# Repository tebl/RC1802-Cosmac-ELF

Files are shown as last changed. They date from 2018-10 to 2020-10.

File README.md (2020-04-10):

# RC1802 Cosmac ELF
There are two ways you can get involved with computers on the nonprofessional level. You can buy one of several reasonably priced hobby computers, with all the added bells and whistles you'd ever want. On the other hand, you can build your own inexpensive system from scratch.

That was rougly the start of the iconic Cosmac ELF-computers history, it was august 1976 and Popular Electronics magazine had just printed the first in a series of tutorials on how everyone could build their own computers using only common parts and the new 1802 processor from RCA.

Back in 2018 this computer still continues to fascinate... several people, definitively me among them so thanks to the glory of the Internet we can still read the original articles online at [American Radio History.Com](https://www.americanradiohistory.com/Popular-Electronics-Guide.htm):
- [1976-08 Build the Cosmac "ELF" Part 1](https://www.americanradiohistory.com/Archive-Poptronics/70s/1976/Poptronics-1976-08.pdf)
- [1976-09 Build the Cosmac "ELF" Part 2](https://www.americanradiohistory.com/Archive-Poptronics/70s/1976/Poptronics-1976-09.pdf)
- [1977-03 How to expand memory, plus more programs](https://www.americanradiohistory.com/Archive-Poptronics/70s/1977/Poptronics-1977-03.pdf)
- [1977-07 Build the PIXIE Graphic Display](https://www.americanradiohistory.com/Archive-Poptronics/70s/1977/Poptronics-1977-07.pdf)

Thankfully someone already made a version of the computer that's available in kit form and in all ways a fantastic piece of kit, that kit is [Lee Hart's 1802 Membership card](http://www.sunrise-ev.com/membershipcard.htm). If you want the whole package, that's the one to get! So, why on earth did I make another one?

Because I wanted the experience on creating one the old fashioned way, also it had a lot of bits and bobs I never could figure out how worked... I don't have a degree in electronics, so every attempt to explain it to me has so far failed so this was my attempt to reduce all the things I didn't understand to just the minimal number of things I don't understand, yet somehow the thing actually works after only five revisions! There were some stupid mistakes done on the first ones, so let's not dig too far back in the commit logs as I'm easily embarrassed.

While the first version had 256 bytes of RAM, this one supports a whopping 64K of addressable memory in the form of two slots that'll take either RAM or ROM! Should be more than enough for anyone, even if you've got ninja skills at toggling in data! Other added features includes extra blinking LEDs, a lot of them!

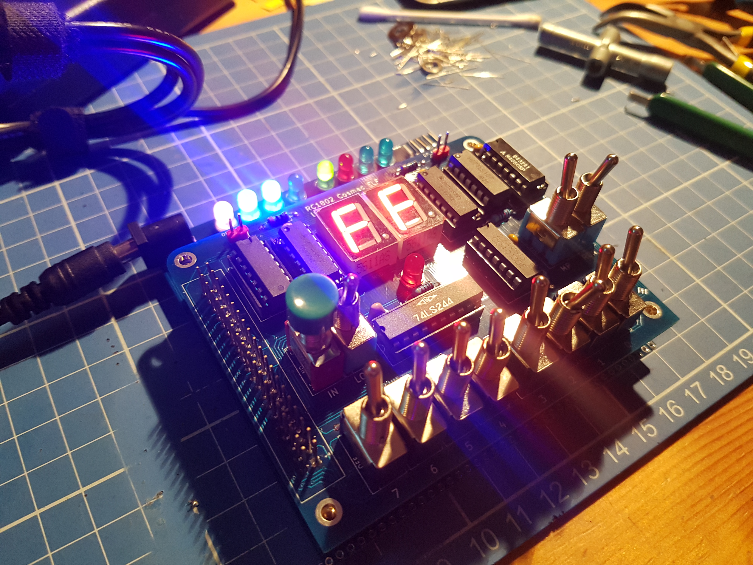
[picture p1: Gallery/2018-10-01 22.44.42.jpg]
RC1802 Computer

RC1802 Modules

## Errata
- UI module revision D had issues where some traces were moved without doing ground plane refill, some lines may appear shorted because of it is. Recommended to replace UI module, but can be cut and rewired according to updated board - see [before](https://github.com/tebl/RC1802-Cosmac-ELF/raw/master/Gallery/1802_ui_d1.PNG) and [after](https://github.com/tebl/RC1802-Cosmac-ELF/raw/master/Gallery/1802_ui_d2.PNG) for reference.
- CPU module revisions D through E had a fault relating to connection of 1802 pin 37 (DMA OUT), mainly that it was never actually connected to anything. Revision F fixes this issue, but you can fix earlier revisions by adding a wire between the bottom of resistor R2 and 1802 pin 37.
- CPU module revision D had **a short** between **GND and VCC**! Later revisions do not have this issue, but if you have this version of the board: please remove pin 40 of the UI connector (top left pin) before attempting to power it up!

## Modules
In order to create a working RC1802 Cosmac ELF computer you will need the following set of modules:
- [CPU Board](https://github.com/tebl/RC1802-Cosmac-ELF/tree/master/RC1802%20CPU) ([order](https://www.pcbway.com/project/shareproject/RC1802_Cosmac_ELF__CPU_module_revision_E_.html?inviteid=88707))
- [User Interface](https://github.com/tebl/RC1802-Cosmac-ELF/tree/master/RC1802%20UI) ([order](https://www.pcbway.com/project/shareproject/RC1802_Cosmac_ELF__UI_module_revision_E_.html?inviteid=88707))

Optional modules:
- [Backplane](https://github.com/tebl/RC6502-Apple-1-Replica/tree/master/RC6502%20Backplane) ([order](https://www.pcbway.com/project/shareproject/RC6502_Apple_1_Replica__Backplane_module_revision_A_.html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))

If you would like to have a copy of one or more modules, what you'll need to do is zip up the contents of the export directory for each module and give that to your favourite PCB fabrication plant. Personally I prefer to use [PCBWay](https://www.pcbway.com/setinvite.aspx?inviteid=88707), each module is only 5$ each and new accounts even get the first one free! Please use the supplied link when signing up to help me support this project, I'll get a small discount on future orders and hopefully I can afford to keep developing new and exciting modules. Even easier, you can just click the orderring-url after each of the modules - that way you'll get something that works on the first try, and you'll support me in a small way for using the URL!

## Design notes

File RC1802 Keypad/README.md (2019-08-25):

# RC1802 Keypad

Toggling in a lot of data, or even just a little bit of data using switches can be a lot of fun... and a lot of work! So in order to keep the fun going I've started experimenting with better switches, this time added the slightly bit newer method of using a hex keypad. This one sort of goes against my design principles of only using the cheapest available alternatives, but only just about by using Gateron keyboard switches instead of those tactile momentary switches. Should be fun!

Note that this is only the mechanical side of things, the logic needed will be made as a separate logic module that hopefully slots in somewhere.

# Schematic
The supplied KiCad files should be sufficient as both a schematic and as a  starting point for ordering PCBs (basically you could just zip the contents of the export folder and upload that on a fabrication site), the schematic is also available in [PDF-format](https://github.com/tebl/RC1802-Cosmac-ELF/raw/master/RC1802%20Keypad/export/RC1802%20Keypad.pdf) and this is what you'll need to print and work your way through this things don't work as expected after assembly.

# BOM
Most parts should be easy to get a hold of from your favourite local electronic component shop though you might have to consider other sources for the older parts such as the CPU and memory. Personally I bought most components with free shipping from China via AliExpress - prices will vary, but I found everything in larger quantities than needed for the cost of a few cups of fancy coffee!

For the pin headers, both male and female - if you can't find the exact pin count, just buy the longer versions and snip off the parts you don't need.

Values in parenthesis is the component amounts that could be considered optional.

| Reference | Item | Count |
| --- | --- | ----- |
| PCB | Fabricate using Gerber files | 1 |
| C1-C6 | 100nF ceramic capacitor | 6 |
| J1 | 2x4 pin header | 1 |
| | 2x4 pin ribbon cable | 1 |
| SW1-SW16 | Gateron 3 or 5 pin switches | 16 |

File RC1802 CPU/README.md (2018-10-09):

# RC1802 CPU Module

Of the two main modules needed for the RC1802 Cosmac ELF computer, this is the main board that includes the RCA 1802 processor along with any RAM and ROM you want. In other words this is the brains of the whole operation! In theory this board by itself should be able to function by itself though the validity of this claim is still lacking some actual testing.

CPU Module

# Schematic
The supplied KiCad files should be sufficient as both a schematic and as a  starting point for ordering PCBs (basically you could just zip the contents of the export folder and upload that on a fabrication site), the schematic is also available in [PDF-format](https://github.com/tebl/RC1802-Cosmac-ELF/raw/master/RC1802%20CPU/export/RC1802%20CPU.pdf) and this is what you'll need to print and work your way through this things don't work as expected after assembly.

# BOM
Most parts should be easy to get a hold of from your favourite local electronic component shop though you might have to consider other sources for the older parts such as the CPU and memory. Personally I bought most components with free shipping from China via AliExpress - prices will vary, but I found everything in larger quantities than needed for the cost of a few cups of fancy coffee! You don't need the newest and fastest components, after all it's going into a 70s-era computer so don't go overboard unless you want to (you can replace 74LS ICs with 74HCT or 74ALS if you want something newer). Most components have been produced by various manufacturers, these mostly do the same thing without any relevant differences though the choice of CPU and PIA could lead to incompatibilities so I've specified the ones I've had success with (probably also the cheapest ones available).

Some vendors will have the same ICs in different form factors, the ones you want will often be specified as being in the form of a DIP/PDIP package. Usually you'll want sockets for each of the ICs as well, a bag of assorted sockets should be easily available without setting you back more than a couple bucks. With the sockets in place, you don't need to dread having to remove an IC later, this leads to easier fault finding and you can even "borrow" them for other projects later! For the pin headers, both male and female - if you can't find the exact pin count, just buy the longer versions and snip off the parts you don't need.

Values in parenthesis is the component amounts that could be considered optional.

| Reference | Item | Count |
| --- | --- | ----- |
| PCB | Fabricate using Gerber files ([order](https://www.pcbway.com/project/shareproject/RC1802_Cosmac_ELF__CPU_module_revision_D_.html))  | 1 |
| C1-C6 | 100nF ceramic capacitor | 6 |
| D1-D8 | 5mm LED (assorted colours) | (8) |
| J5 | 1x39 right-angle pin header | (1) |
| J6 | 2x20 pin header | 1 |
| J7 | 3 pin DC barrel connector | 1 |
| J8 | 1x05 pin header | 1 |
| J9 | 1x04 pin header | 1 |
| JP2-JP6 | 1x03 pin header | 5 |
| R1-R7 | 47k ohm resistor | 7 |
| R8-R15 | 220 ohm resistor | (8) |
| U1 | 74LS04 DIP-14 | 1 |
| U2 | CDP1802 CPU DIP-40 | 1 |
| U3 | 74LS240 DIP-20 | (1) |
| U4 | 74LS373 DIP-20 | 1 |
| U5-U6 | 62256 Static RAM DIP-28 | 1 (1) |
| X1 | 1.000Mhz TTL Oscillator, (DIP 14) | 1 |

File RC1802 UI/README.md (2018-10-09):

# RC1802 User Interface Module

Of the two main modules needed for the RC1802 Cosmac ELF computer, this board contains all the switches you'll need to toggle in data untill you can toggle no more! Also includes the two seven segment displays used as user feedback and output.

UI Module

# Schematic
The supplied KiCad files should be sufficient as both a schematic and as a  starting point for ordering PCBs (basically you could just zip the contents of the export folder and upload that on a fabrication site), the schematic is also available in [PDF-format](https://github.com/tebl/RC1802-Cosmac-ELF/raw/master/RC1802%20UI/export/RC1802%20UI.pdf) and this is what you'll need to print and work your way through this things don't work as expected after assembly.

# BOM
Most parts should be easy to get a hold of from your favourite local electronic component shop though you might have to consider other sources for the older parts such as the CPU and memory. Personally I bought most components with free shipping from China via AliExpress - prices will vary, but I found everything in larger quantities than needed for the cost of a few cups of fancy coffee! You don't need the newest and fastest components, after all it's going into a 70s-era computer so don't go overboard unless you want to (you can replace 74LS ICs with 74HCT or 74ALS if you want something newer). Most components have been produced by various manufacturers, these mostly do the same thing without any relevant differences though the choice of CPU and PIA could lead to incompatibilities so I've specified the ones I've had success with (probably also the cheapest ones available).

Some vendors will have the same ICs in different form factors, the ones you want will often be specified as being in the form of a DIP/PDIP package. Usually you'll want sockets for each of the ICs as well, a bag of assorted sockets should be easily available without setting you back more than a couple bucks. With the sockets in place, you don't need to dread having to remove an IC later, this leads to easier fault finding and you can even "borrow" them for other projects later! For the pin headers, both male and female - if you can't find the exact pin count, just buy the longer versions and snip off the parts you don't need.

Values in parenthesis is the component amounts that could be considered optional.

| Reference | Item | Count |
| --- | --- | ----- |
| PCB | Fabricate using Gerber files ([order](https://www.pcbway.com/project/shareproject/W217819ASE8_RC1802_UI.html))  | 1 |
| C1-C7 | 100nF ceramic capacitor | 7 |
| D1 | 5mm LED (assorted colours) | 1 |
| D2-D7 | 1N4148 DO-35 | 1 |
| J6 | 2x20 female pin header | 1 |
| JP1-JP2 | 1x02 pin header | (2) |
| AFF1,AFF2 | 7-segment display (common cathode) | 2 |
| R1 | 470 ohm resistor | 1 |
| R2,R3 | 47k ohm resistor | 2 |
| R4,R5 | 330 ohm resistor | 2 |
| SW1, SW3-SW12| 3-pin SPDT mini toggle switch | 11 |
| SW2 | 3-pin SPDT momentary button NO-COM-NC | 1 |
| U1 | 74LS04 DIP-14 | 1 |
| U2 | CD4050 DIP-16 | 1 |
| U3 | CD4013 DIP-14 | 1 |
| U4 | 74LS10 DIP-14 | 1 |
| U5,U7 | MC14495P1 DIP-14 | 2 |
| U6 | 74LS244 DIP-20 | 1 |

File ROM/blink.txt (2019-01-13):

Flash blink.hex to 28C256 (yes, I know thats about 99,9% waste of space). Put into slot mapped into low memory to run the code directly (WE switch for this slot in the upper position), this is done by raising toggle switch marked RUN.

If used with slot mapped to upper memory, need to toggle in a short program into lower RAM memory (WE switch for this slot in the lower position) to jump to $8000 (address 8000 in hex). To do this, put all switches (LOAD/MP/RUN) in lower position. Then raise LOAD switch, then toggle in the data listed below. Push IN after each line/byte, the hex display should echo the same byte after.

HEX Binary    Comment
C0  1100 0000 LBR
80  1000 0000 80
00  0000 0000 00

Finish data entry by lowering LOAD switch, to verify that data entered is correct start by raising switch MP (Memory Protect) and then raising LOAD again. Press IN to have the RC6502 computer echo back each byte of data. To correct changes you need to toggle (down and then up again) the LOAD switch to reset the program counter. Keep MP raised and step through until the byte BEFORE the one with the error, lower the MP switch and input the correct byte. Push IN and see that the correct byte was now echoed back, if only changing that one byte - raise the MP switch again and use IN to step through the remaining data.

When satisfied, lower all switches and then raise the RUN switch to have the computer execute the data entered into RAM. It will now jump to the ROM mapped into high memory, if it everything works as expected you should see the computer start to blink it's Q-led.

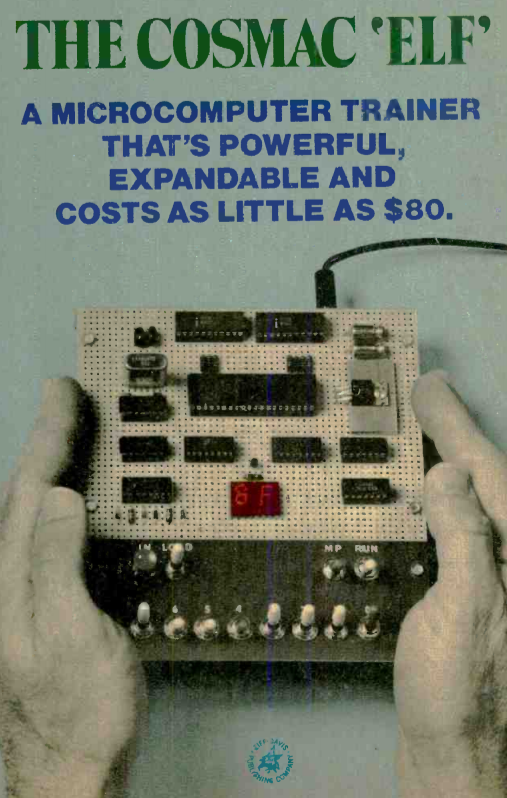
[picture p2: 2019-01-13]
Gallery/Popular Electronics 1976-08 (clipped).PNG

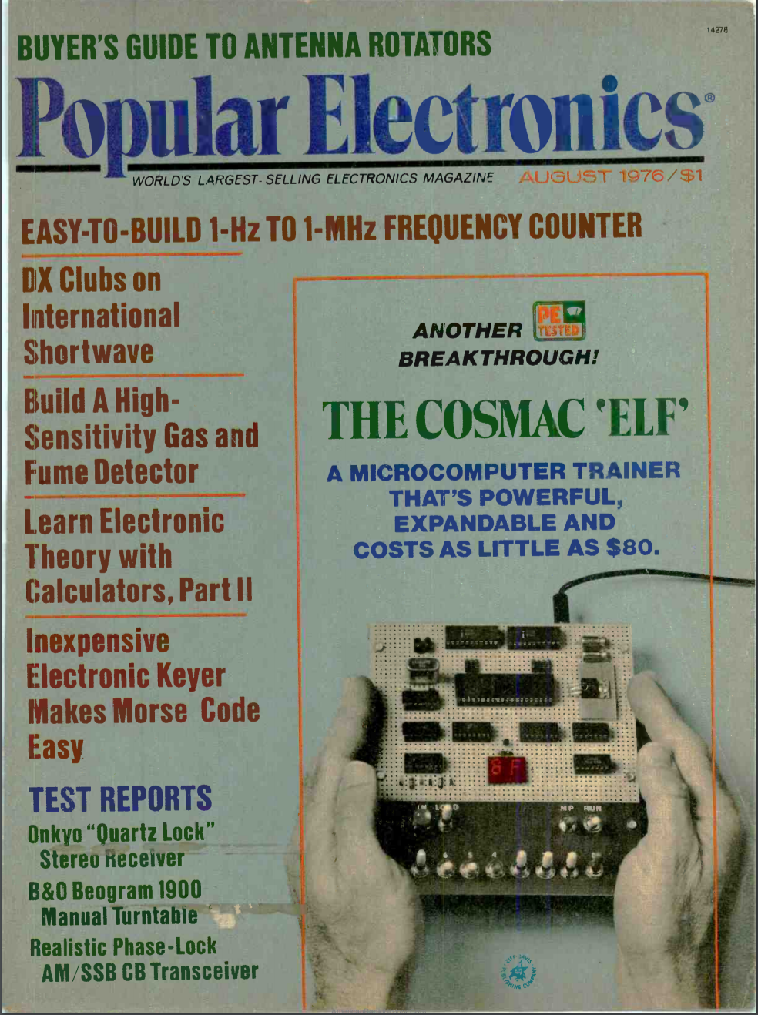
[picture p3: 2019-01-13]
Gallery/Popular Electronics 1976-08.PNG

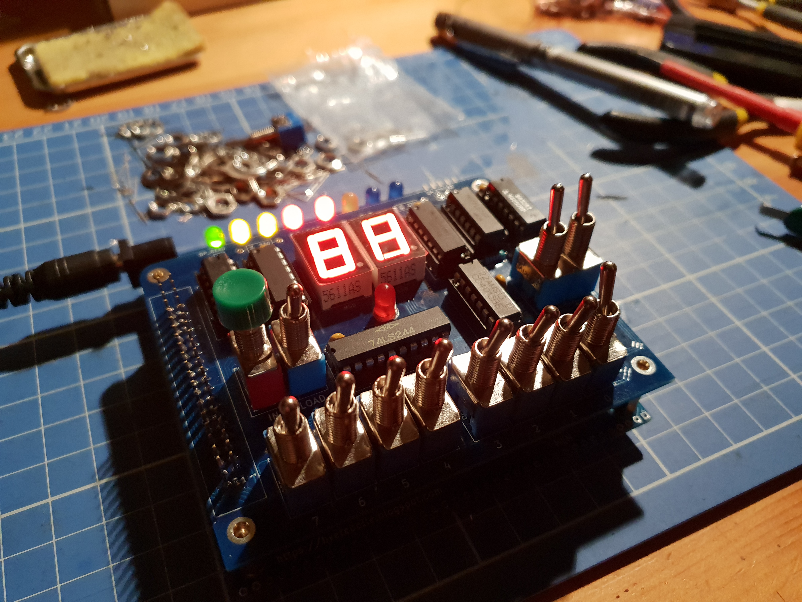
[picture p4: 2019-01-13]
Gallery/2018-11-03 01.10.08.jpg

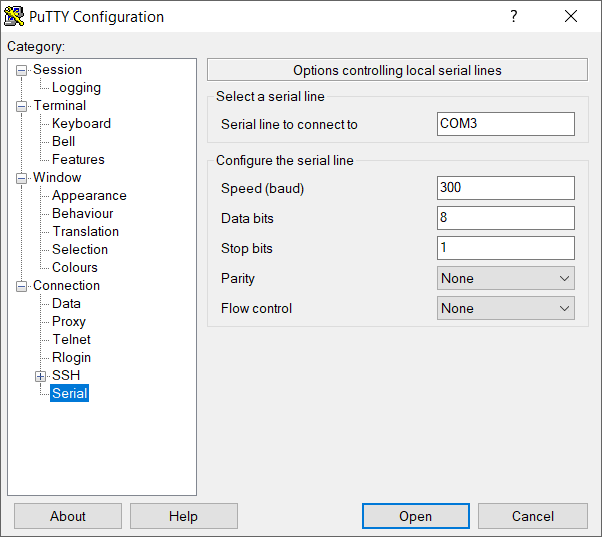
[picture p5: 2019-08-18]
Gallery/Loopback_002.PNG

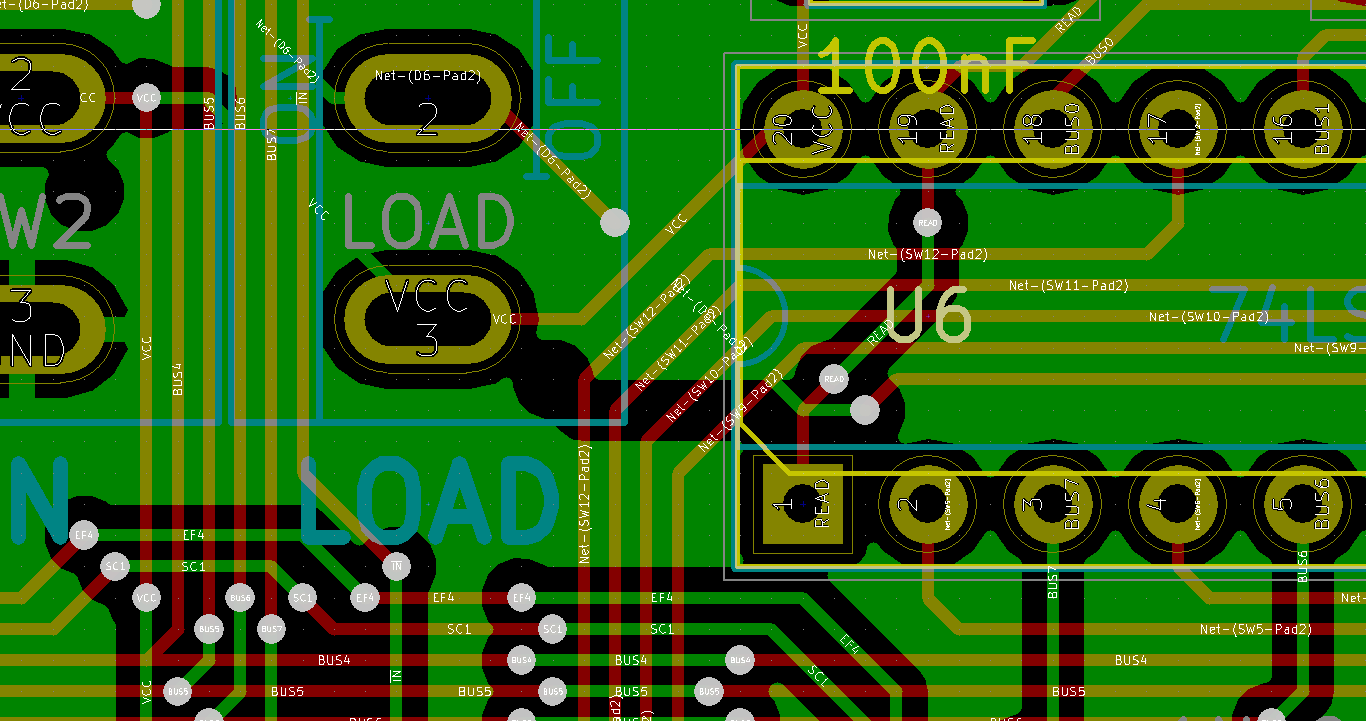
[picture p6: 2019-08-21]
Gallery/1802_ui_d1.PNG

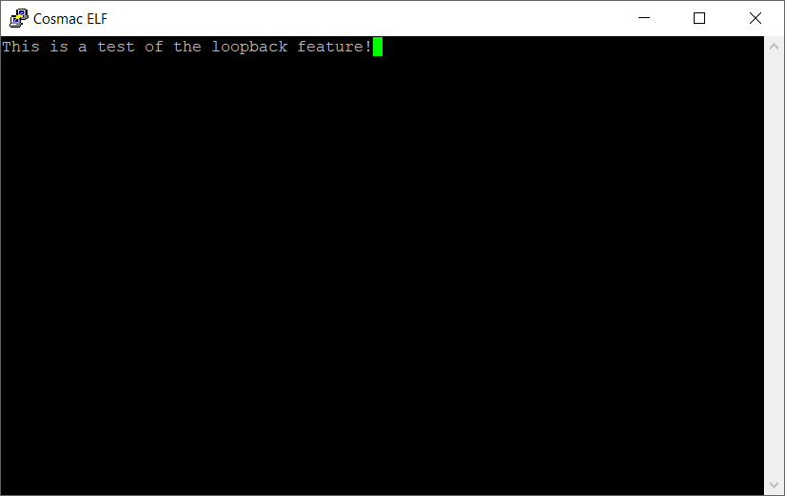
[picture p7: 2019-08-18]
Gallery/Loopback_003.PNG

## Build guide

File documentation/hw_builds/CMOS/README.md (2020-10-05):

# RC1802 CMOS Build
David Madole made a specialized build of the RC1802 using CMOS chips exclusively, the following post from the Cosmac Elf group on [groups.io](https://groups.io/g/cosmacelf) have been included with his permission. Exciting stuff!

## Details
> I completed my RC1802 today with the arrival of the last piece, the MC14495 chips.
>
> I build it as a CMOS version, substituting 74C chips for the 74LS ones and I added pull-up resistors on some of the switches so that inputs aren’t left floating when the switch is in transition since the 74C chips don’t have internal pull-ups. This could be especially important on the MP switch so it doesn’t glitch a write when the switch is flipped.
>
> The options to display the READ and STROBE signals using the decimal points can’t be used as the LED is driven directly from the logic signal and the LED loads the voltage down too much to be seen as a high by the CMOS chips. That would be easy to fix using extra gates on the CD4050 to drive the LEDs separately. I am not sure if I will bother to modify it for that or not since I am not sure that feature is useful to me anyway.
>
> Other than those two things, the conversion to CMOS is pretty painless and all the chips were made in 74C versions (and I even had most of them already in fact). I am probably going to adjust some of the dropping resistor values to decrease the status LED brightness a bit.
>
> Besides toggling in code, I also burned the BASIC3 ROM image from the membership card site to a 27C128 and addressed it at zero and it fired right up into BASIC.  I am using a 1.832 MHz oscillator instead of the 1 MHz specified for a little more speed and also because I may build a PIXIE card for it so I wanted to make sure it runs ok at about that frequency. The BASIC ROM ran 9600 baud fine with this frequency.
>
> I really like the 100mm x 100mm format, I was working on a design of my own for a machine based on that happens to be similar to the RC1802 so when I learned of it I decided to build it first and see how and what I liked on it. It’s a neat little machine, especially as CMOS, I may build an expansion card or two for it.
>
> Photos attached. Some were taken before the MC14495’s arrived so those sockets are empty and the display blank. But there is one I took today with the display in action also.
>
> Special thanks to P. Todd Decker for hooking me up with the boards!
>
> David

## Pictures
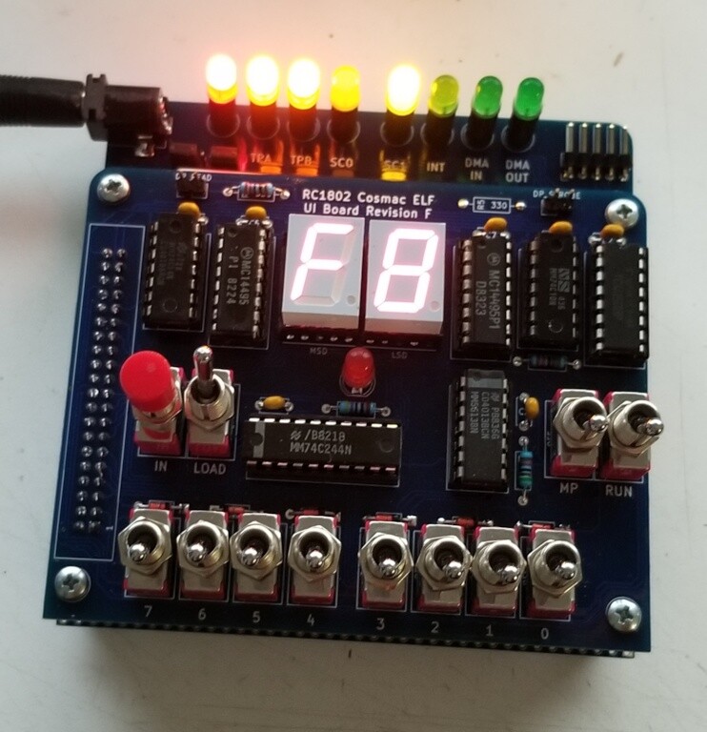
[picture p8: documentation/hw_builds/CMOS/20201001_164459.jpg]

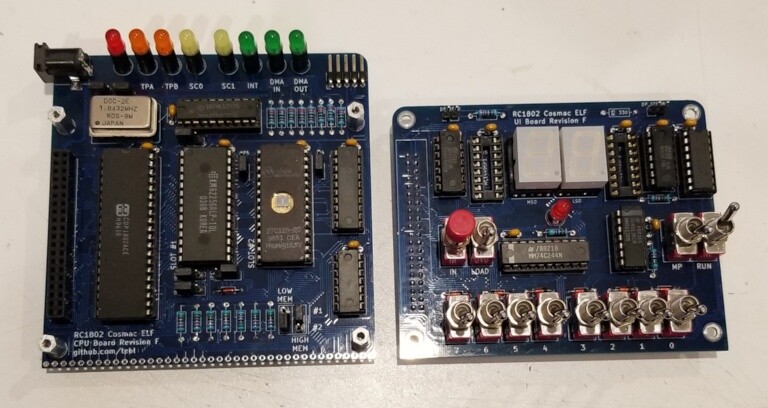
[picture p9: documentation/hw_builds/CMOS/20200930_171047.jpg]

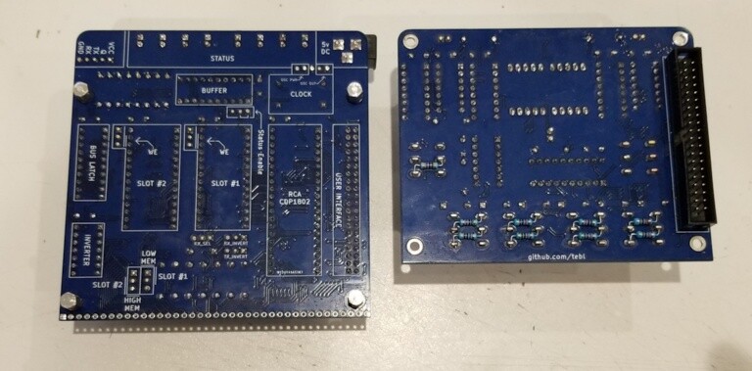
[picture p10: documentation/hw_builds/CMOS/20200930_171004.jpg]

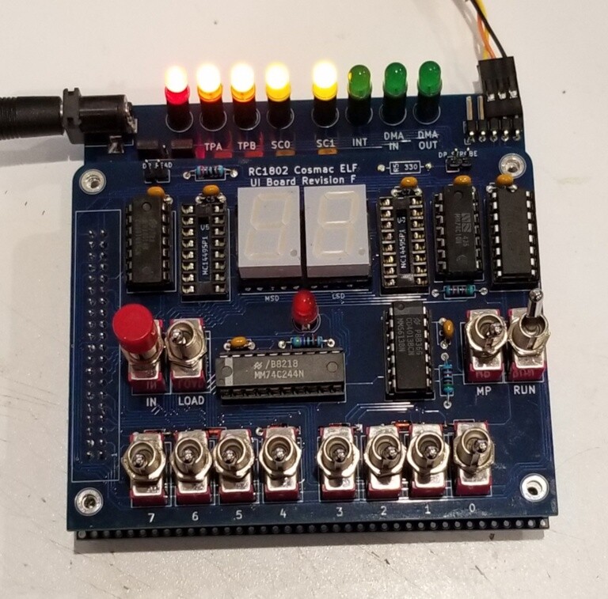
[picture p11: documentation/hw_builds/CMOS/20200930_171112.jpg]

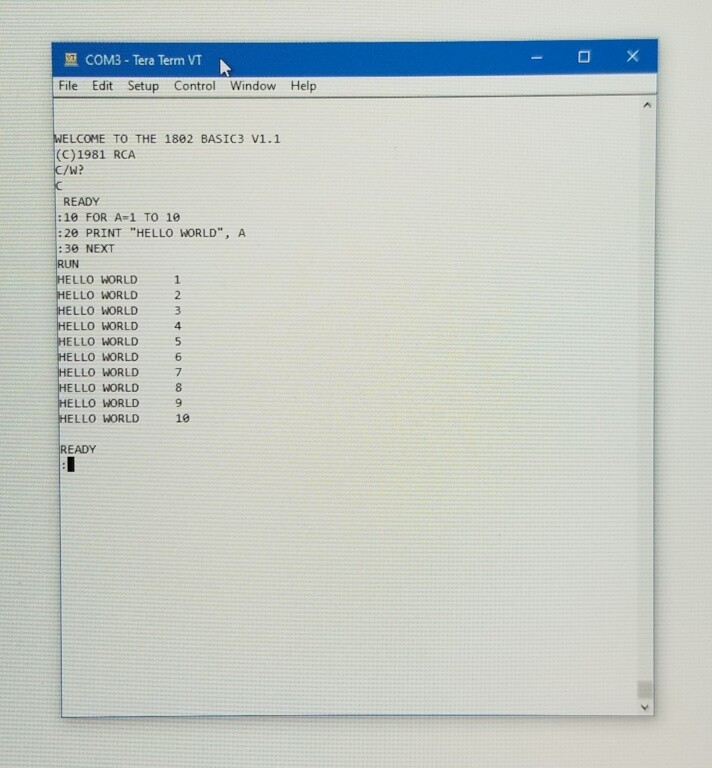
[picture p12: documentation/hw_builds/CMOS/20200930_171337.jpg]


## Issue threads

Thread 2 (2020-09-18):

Serial support - trying to run IDIOT monitor

GrantMeStrength, 2020-09-18:
Are there any special issues with Rev F when it comes to serial support? I’ve been trying to get Serial working for a while now, and have had limited success - it ran once, and I’ve never been able to repeat it. The CPU is definitely running, and a loop back program convinces me the serial ports are working, but IDIOT is stubborn. Any advice welcome!

GrantMeStrength, 2020-09-26:
Ah! Following a discussion on https://groups.io/g/cosmacelf/topics it seems that the logic chips - and U4 on the UI board in particular - should be a CMOS not LS type. Otherwise, replace R3 on the UI board with a 3K3 resistor instead of the 47K. Once I did this, my Elf worked. Thanks!

Closed 2020-09-26.

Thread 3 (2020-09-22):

Digikey BOM Accuracy

ptdecker, 2020-09-22:
Good morning!

I have been trying to pull together a BOM for the RC1802 (all three cards).  Is there any way someone could double-check this list--especially the items in yellow and then in orange--for accuracy?  These specific items are the connectors, switches, and 7-Segment displays.  I have found these particular kinds of parts hard to get correct.

As a side note, I am able to source most of the components from Digikey with the exception of some of the ICs (and, of course, the 1802 itself).

https://docs.google.com/spreadsheets/d/1LfU8H-aynhVCH4n1tYR6aGqn6C8KZxggnxihwcBkzcY/edit?usp=sharing

P. Todd

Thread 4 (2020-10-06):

Question regarding RUN->CLEAR circuitry

hanshuebner, 2020-10-06:
Hey,

I am building your computer, thank you for publishing it!  While working on it, I found this in the schematics of the I/O board:

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

I wonder if this is a mistake or whether something is going on which is beyond my limited knowledge of electronics and CMOS buffers.  It looks as if the input of the buffer is directly connected to the output, so what can the buffer do here?

Thanks again! Hans

dmadole, 2020-10-10:
It is used to debounce the switch. Basically the buffer will hold whatever signal is forced onto it. By shorting the input to VCC or Ground you can override what state it's in already e.g. it's it's high you can force it to low by grounding the input. Yes, this grounds the output also but the CMOS outputs are current limited and it's harmless to do so, especially for the tens of microseconds until the gate changes level.

hanshuebner, 2020-10-11:
Thank you for the explanation!

Closed 2020-10-11.

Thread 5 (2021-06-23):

Resistor values

dmadole, 2021-06-23:
The 47K pull-down resistors in the diode-logic gates are too weak to pull down the LSTTL inputs causing the display and input port to be enabled when they shouldn'tbe . Replace with 4.7K to fix.

Replacing the 47K resistors on the CPU card with 4.7K is a good idea also if the bus is expanded. The 4.7K resistors on both cards are better even when using CMOS.

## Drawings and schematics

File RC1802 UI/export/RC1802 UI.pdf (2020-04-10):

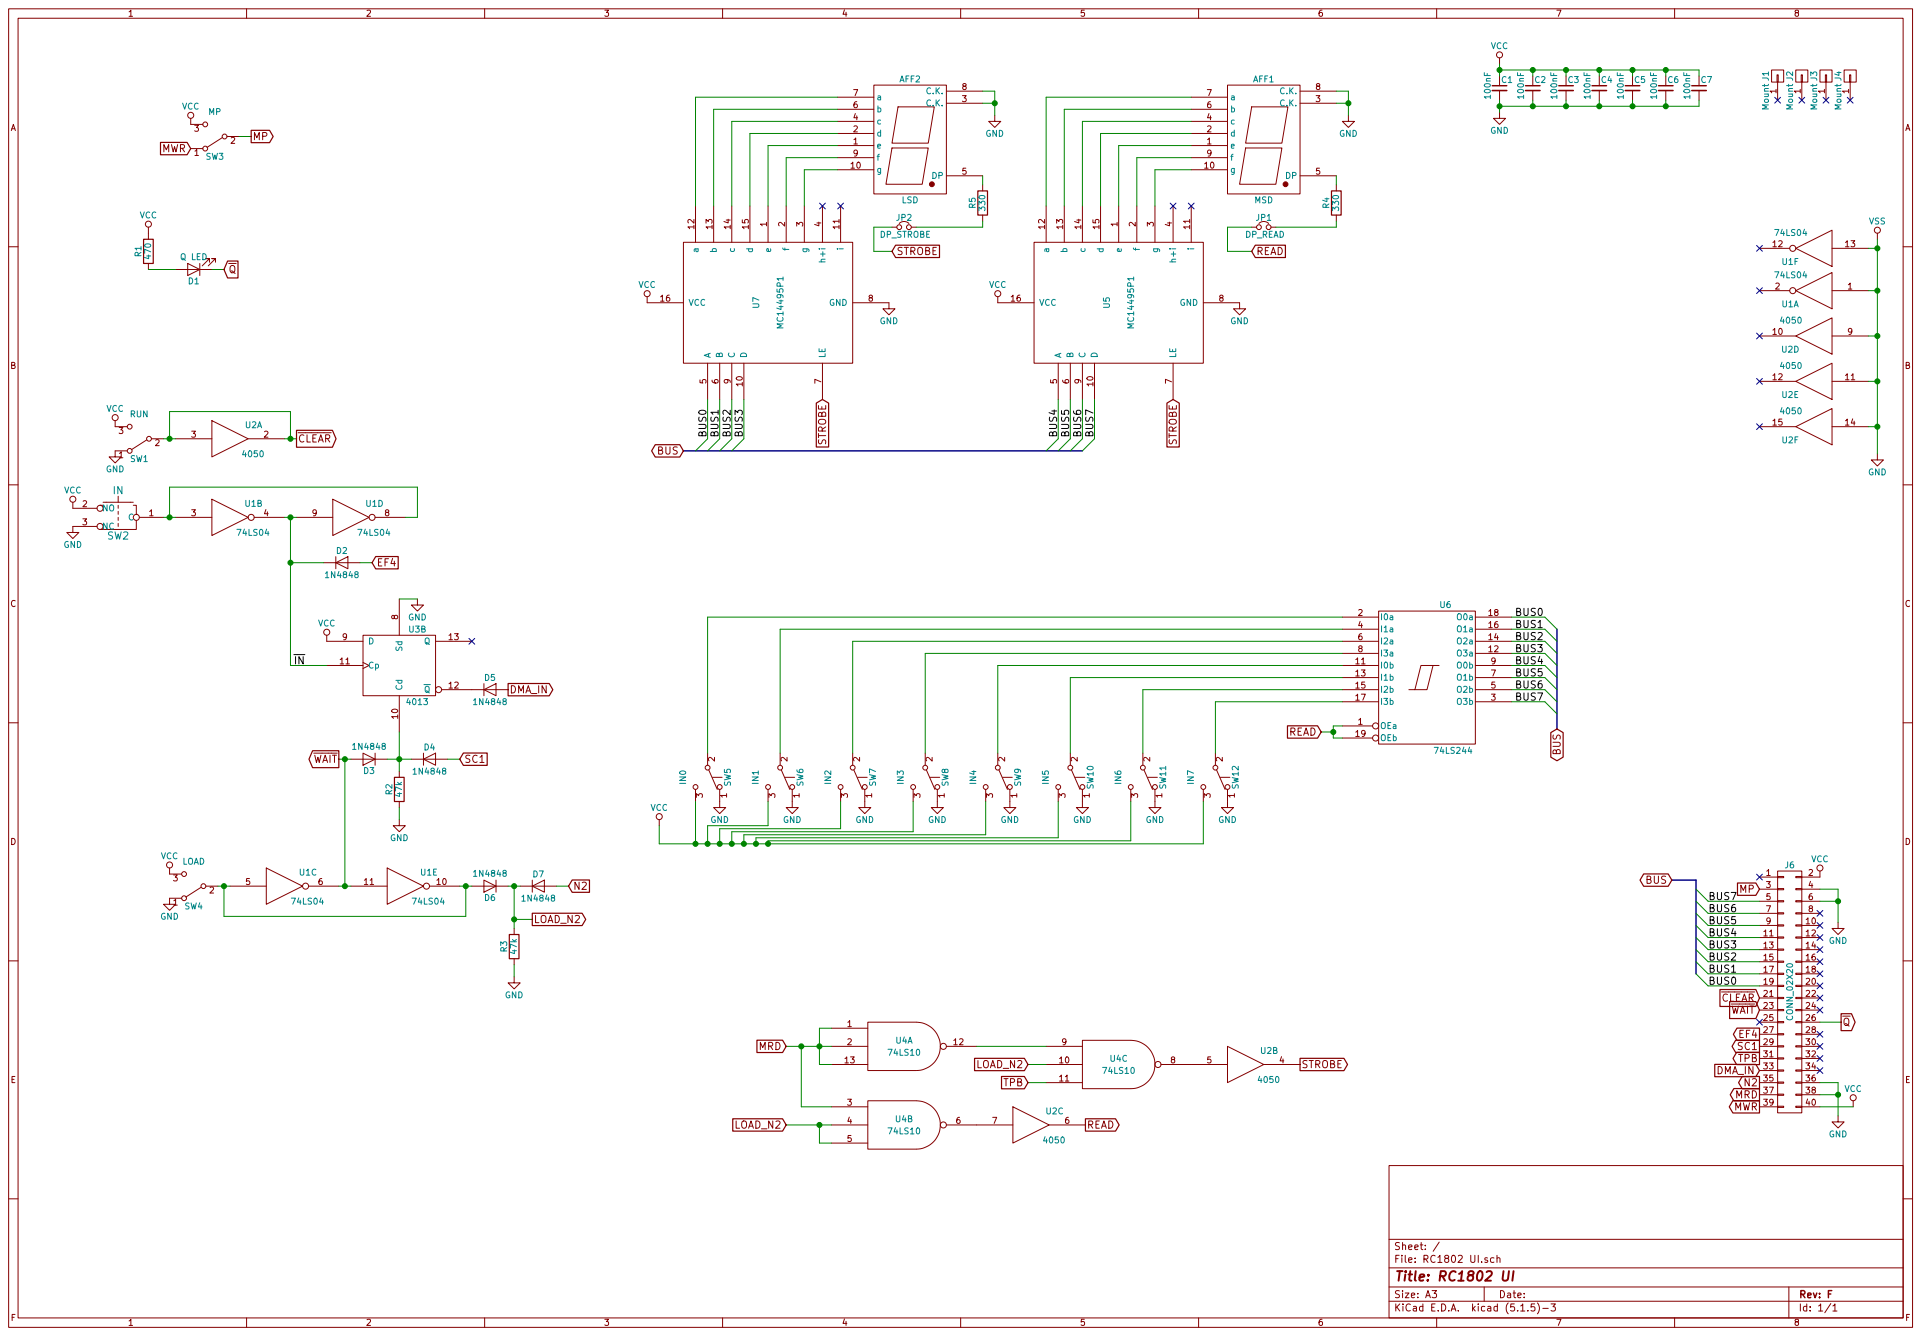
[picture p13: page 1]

1 J1 Mount 1 J2 Mount 1 J3 Mount 1 J4 Mount R1 470

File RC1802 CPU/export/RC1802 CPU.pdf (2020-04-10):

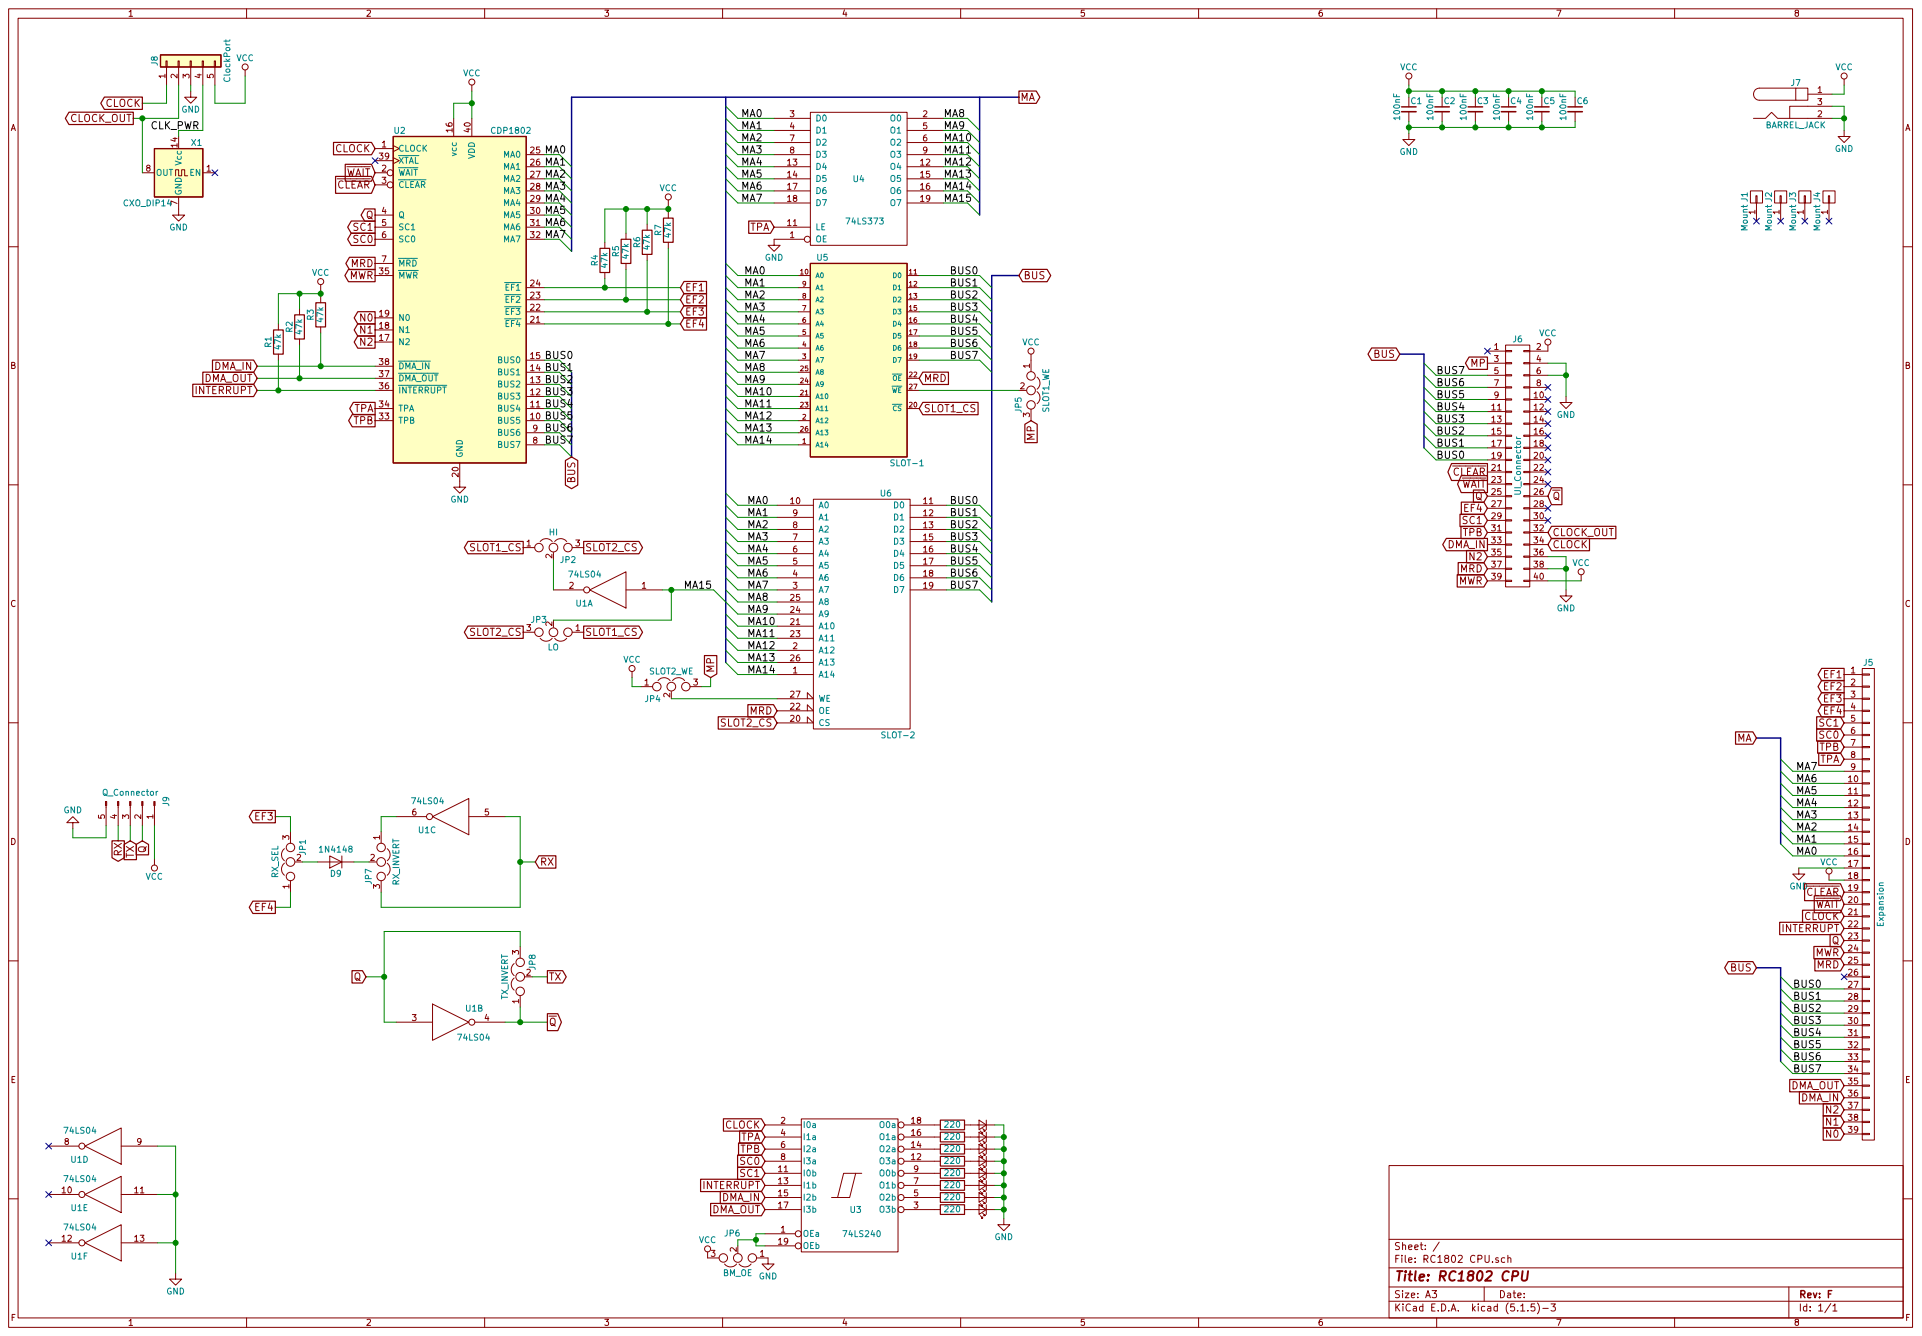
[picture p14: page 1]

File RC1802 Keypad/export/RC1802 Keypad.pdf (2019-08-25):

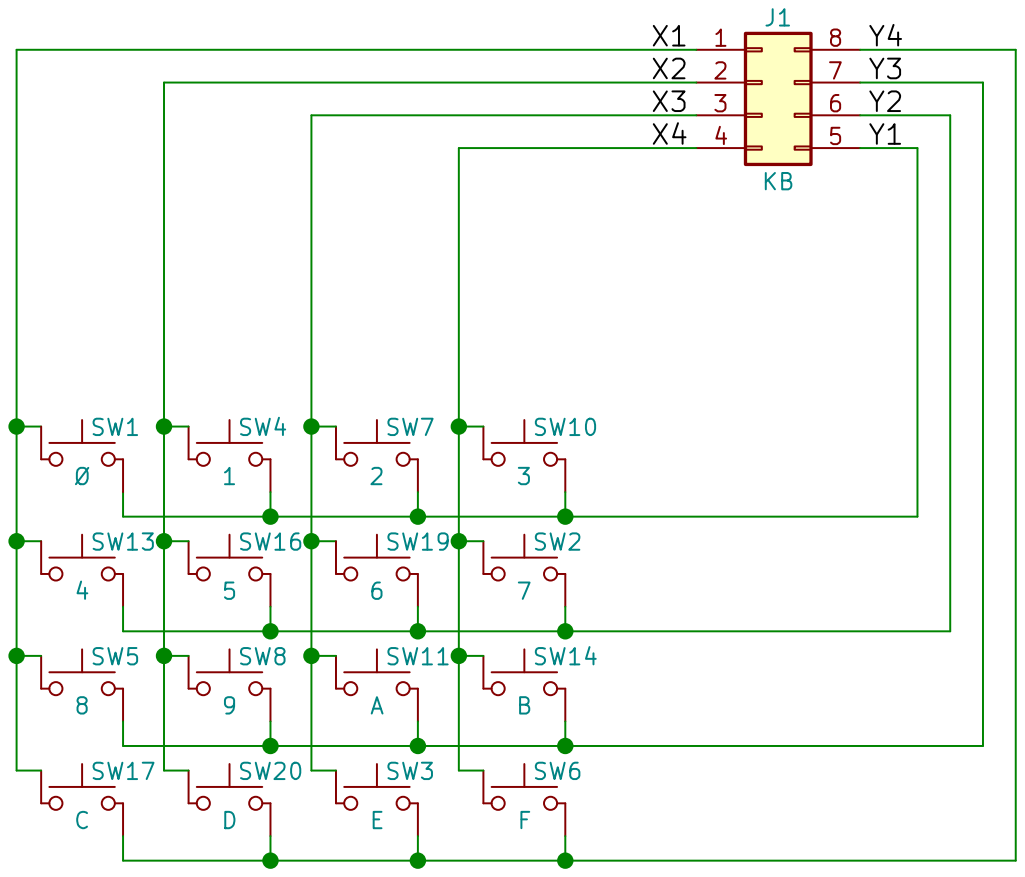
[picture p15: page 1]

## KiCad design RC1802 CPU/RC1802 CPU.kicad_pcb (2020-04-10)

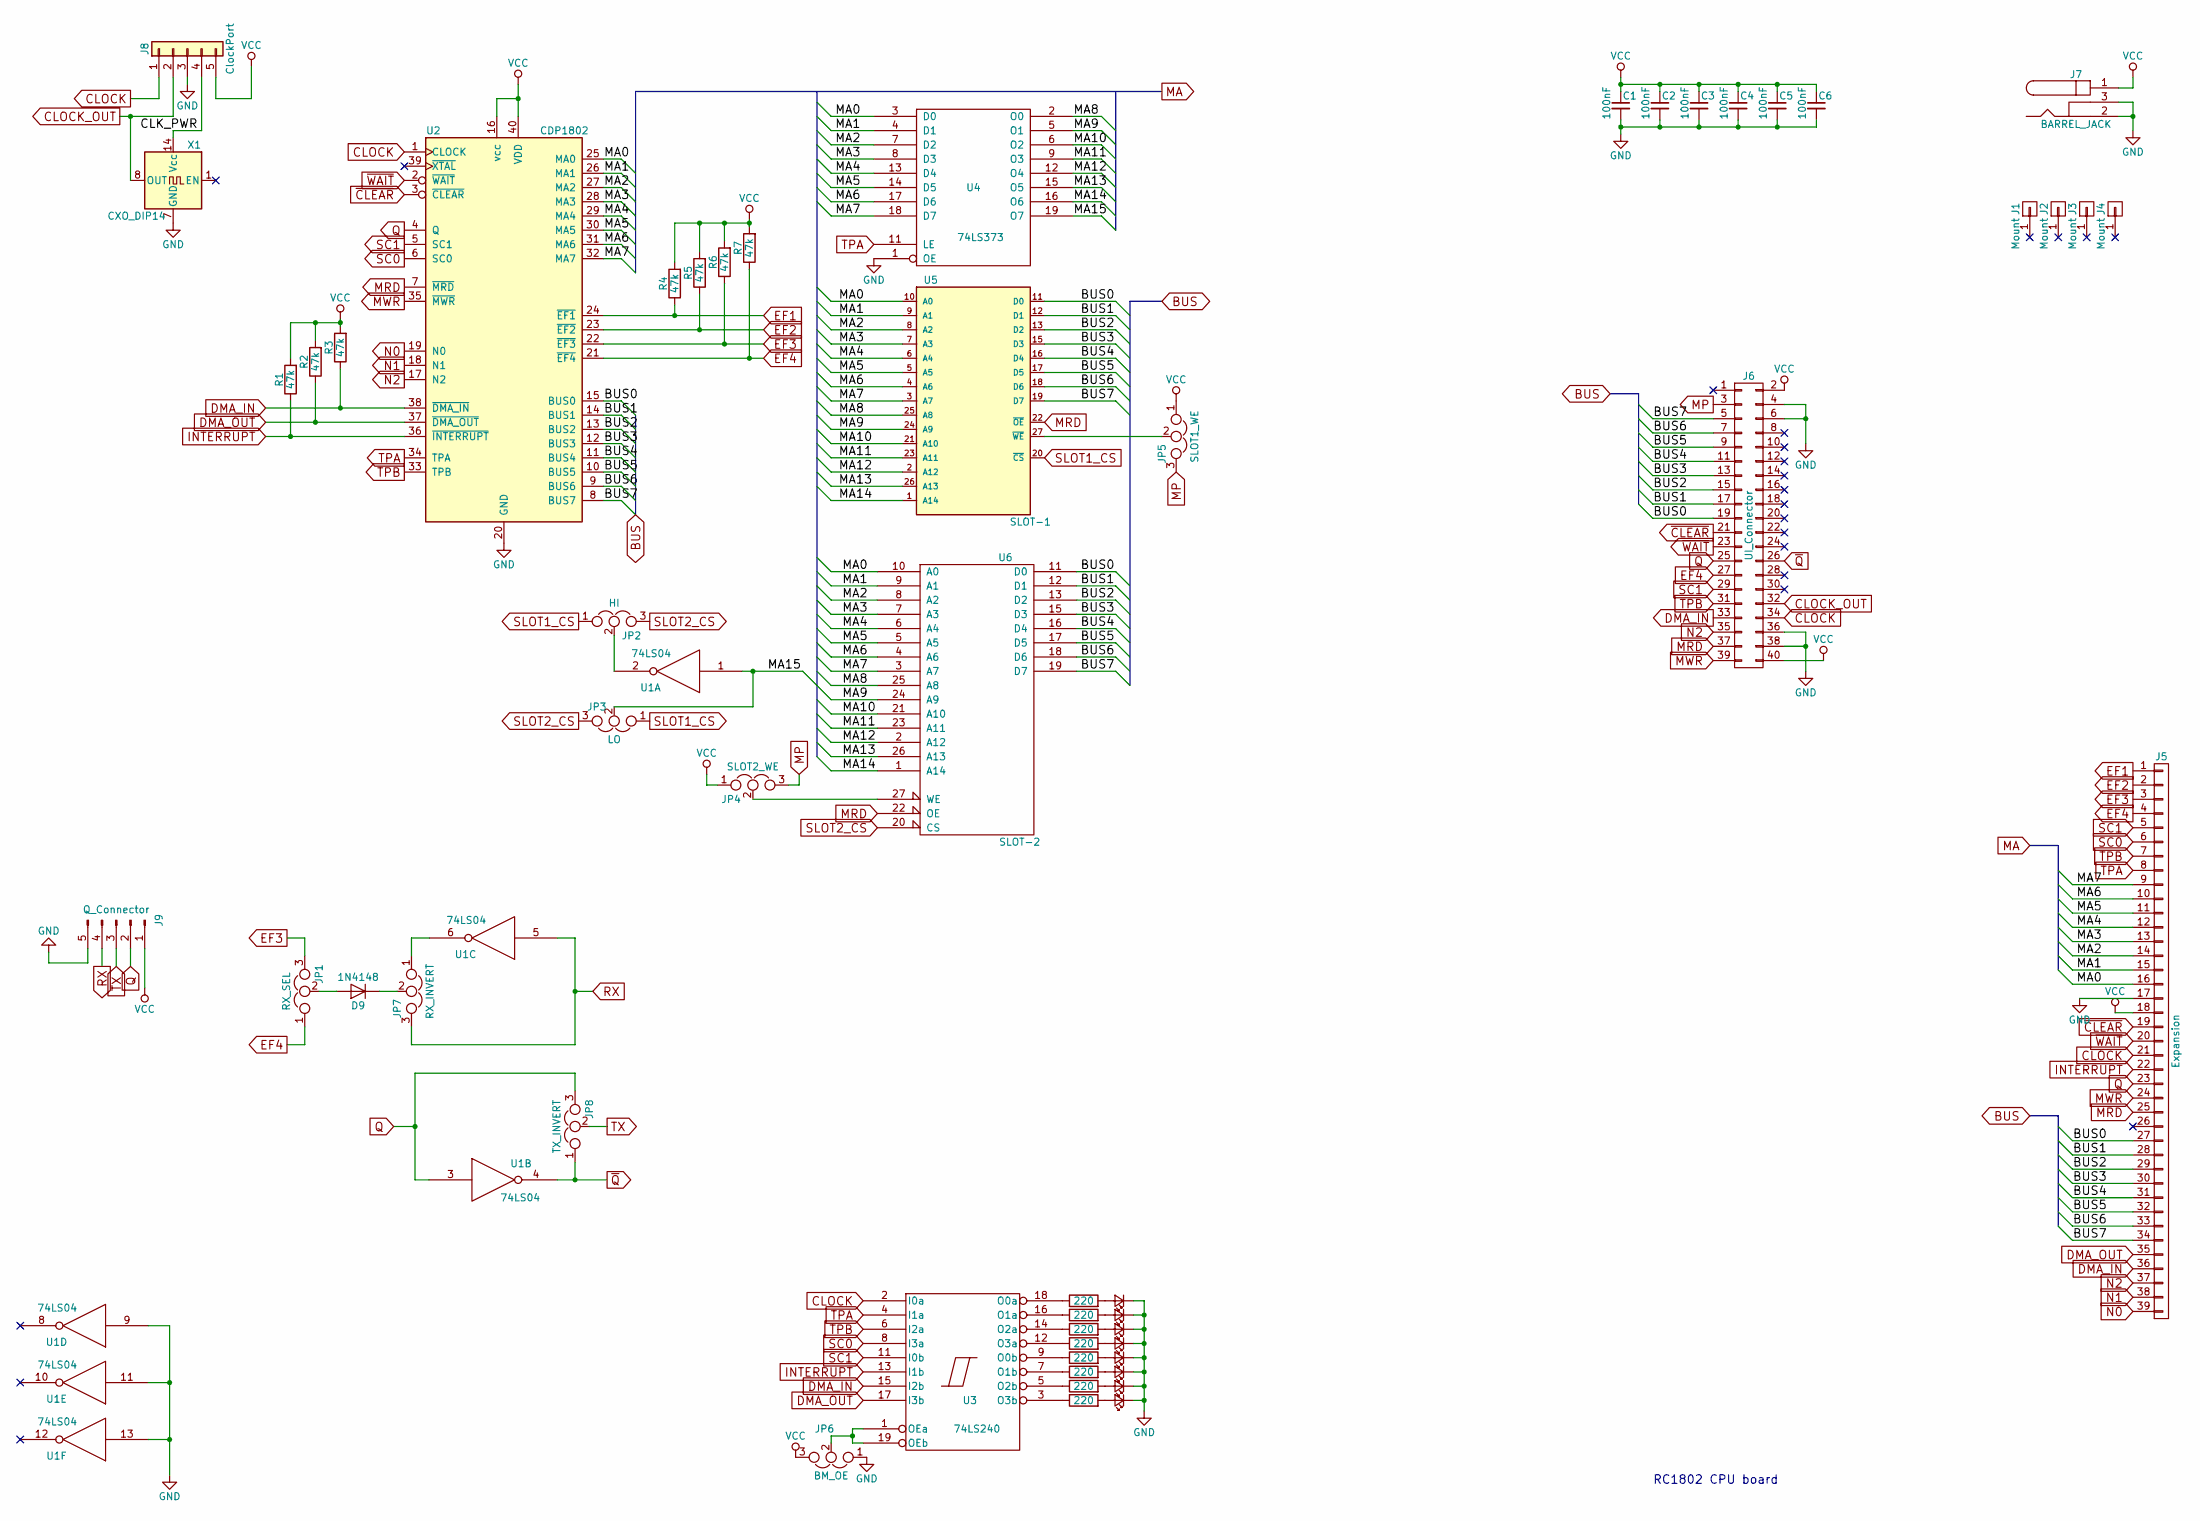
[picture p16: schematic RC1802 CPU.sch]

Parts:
C1, C2, C3, C4, C5, C6: 100nF; C_Disc_D4.7mm_W2.5mm_P5.00mm
D1, D2, D3, D4, D5, D6, D7, D8: LED_Small; LED_D5.0mm
D9: 1N4148; D_DO-35_SOD27_P7.62mm_Horizontal
J1, J2, J3, J4: Mount; 1pin
J5: Expansion; Pin_Header_Angled_1x39_Pitch2.54mm
J6: UI_Connector; Pin_Header_Straight_2x20_Pitch2.54mm
J7: BARREL_JACK
J8: ClockPort; Pin_Header_Straight_1x05_Pitch2.54mm
J9: Q_Connector; Pin_Header_Angled_1x05_Pitch2.54mm
JP1: RX_SEL; Pin_Header_Straight_1x03_Pitch2.54mm
JP2: HI; Pin_Header_Straight_1x03_Pitch2.54mm
JP3: LO; Pin_Header_Straight_1x03_Pitch2.54mm
JP4: SLOT2_WE; Pin_Header_Straight_1x03_Pitch2.54mm
JP5: SLOT1_WE; Pin_Header_Straight_1x03_Pitch2.54mm
JP6: BM_OE; Pin_Header_Straight_1x03_Pitch2.54mm
JP7: RX_INVERT; Pin_Header_Straight_1x03_Pitch2.54mm
JP8: TX_INVERT; Pin_Header_Straight_1x03_Pitch2.54mm
R1, R2, R3, R4, R5, R6, R7: 47k; R_Axial_DIN0207_L6.3mm_D2.5mm_P10.16mm_Horizontal
R8, R9, R10, R11, R12, R13, R14, R15: 220; R_Axial_DIN0207_L6.3mm_D2.5mm_P10.16mm_Horizontal
U1: 74LS04; DIP-14_W7.62mm_Socket
U2: CDP1802; DIP-40_W15.24mm_Socket
U3: 74LS240; DIP-20_W7.62mm_Socket
U4: 74LS373; DIP-20_W7.62mm_Socket
U5: SLOT-1; DIP-28_W15.24mm_Socket
U6: SLOT-2; DIP-28_W15.24mm_Socket
X1: CXO_DIP14; Oscillator_DIP-14

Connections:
/BUS0: J5.27, J6.19, U2.15 (BUS0), U5.11 (D0), U6.11 (D0)
/BUS1: J5.28, J6.17, U2.14 (BUS1), U5.12 (D1), U6.12 (D1)
/BUS2: J5.29, J6.15, U2.13 (BUS2), U5.13 (D2), U6.13 (D2)
/BUS3: J5.30, J6.13, U2.12 (BUS3), U5.15 (D3), U6.15 (D3)
/BUS4: J5.31, J6.11, U2.11 (BUS4), U5.16 (D4), U6.16 (D4)
/BUS5: J5.32, J6.9, U2.10 (BUS5), U5.17 (D5), U6.17 (D5)
/BUS6: J5.33, J6.7, U2.9 (BUS6), U5.18 (D6), U6.18 (D6)
/BUS7: J5.34, J6.5, U2.8 (BUS7), U5.19 (D7), U6.19 (D7)
/CLK_PWR: J8.4, X1.14 (Vcc)
/MA0: J5.16, U2.25 (MA0), U4.3 (D0), U5.10 (A0), U6.10 (A0)
/MA1: J5.15, U2.26 (MA1), U4.4 (D1), U5.9 (A1), U6.9 (A1)
/MA2: J5.14, U2.27 (MA2), U4.7 (D2), U5.8 (A2), U6.8 (A2)
/MA3: J5.13, U2.28 (MA3), U4.8 (D3), U5.7 (A3), U6.7 (A3)
/MA4: J5.12, U2.29 (MA4), U4.13 (D4), U5.6 (A4), U6.6 (A4)
/MA5: J5.11, U2.30 (MA5), U4.14 (D5), U5.5 (A5), U6.5 (A5)
/MA6: J5.10, U2.31 (MA6), U4.17 (D6), U5.4 (A6), U6.4 (A6)
/MA7: J5.9, U2.32 (MA7), U4.18 (D7), U5.3 (A7), U6.3 (A7)
/MA8: U4.2 (O0), U5.25 (A8), U6.25 (A8)
/MA9: U4.5 (O1), U5.24 (A9), U6.24 (A9)
/MA10: U4.6 (O2), U5.21 (A10), U6.21 (A10)
/MA11: U4.9 (O3), U5.23 (A11), U6.23 (A11)
/MA12: U4.12 (O4), U5.2 (A12), U6.2 (A12)
/MA13: U4.15 (O5), U5.26 (A13), U6.26 (A13)
/MA14: U4.16 (O6), U5.1 (A14), U6.1 (A14)
/MA15: JP3.2, U1.1, U4.19 (O7)
CLOCK: J5.21, J6.34, J8.1, U2.1 (CLOCK), U3.2 (I0a)
CLOCK_OUT: J6.32, J8.2, X1.8 (OUT)
DMA_IN: J5.36, J6.33, R3.1, U2.38 (~DMA_IN), U3.15 (I2b)
DMA_OUT: J5.35, R2.1, U2.37 (~DMA_OUT), U3.17 (I3b)
EF1: J5.1, R4.1, U2.24 (~EF1)
EF2: J5.2, R5.1, U2.23 (~EF2)
EF3: J5.3, JP1.3, R6.1, U2.22 (~EF3)
EF4: J5.4, J6.27, JP1.1, R7.1, U2.21 (~EF4)
GND: C1.2, C2.2, C3.2, C4.2, C5.2, C6.2, D1.1 (K), D2.1 (K), D3.1 (K), D4.1 (K), D5.1 (K), D6.1 (K), D7.1 (K), D8.1 (K), J5.17, J6.4, J6.6, J6.36, J6.38, J7.2, J7.3, J8.3, J9.5, JP6.1, U1.7 (GND), U1.9, U1.11, U1.13, U2.20 (GND), U3.10 (GND), U4.1 (OE), U4.10 (GND), U5.14 (GND), U6.14 (GND), X1.7 (GND)
INTERRUPT: J5.22, R1.1, U2.36 (~INTERRUPT), U3.13 (I1b)
MP: J6.3, JP4.3, JP5.3
MRD: J5.25, J6.37, U2.7 (~MRD), U5.22 (~OE), U6.22 (OE)
MWR: J5.24, J6.39, U2.35 (~MWR)
N0: J5.39, U2.19 (N0)
N1: J5.38, U2.18 (N1)
N2: J5.37, J6.35, U2.17 (N2)
unnamed: D1.2 (A), R8.2
unnamed: D2.2 (A), R9.2
unnamed: D3.2 (A), R10.2
unnamed: D4.2 (A), R11.2
unnamed: D5.2 (A), R12.2
unnamed: D6.2 (A), R13.2
unnamed: D7.2 (A), R14.2
unnamed: D8.2 (A), R15.2
unnamed: D9.1 (K), JP7.2
unnamed: D9.2 (A), JP1.2
unnamed: JP2.2, U1.2
unnamed: JP4.2, U6.27 (WE)
unnamed: JP5.2, U5.27 (~WE)
unnamed: JP6.2, U3.1 (OEa), U3.19 (OEb)
unnamed: JP7.1, U1.6
unnamed: R8.1, U3.18 (O0a)
unnamed: R9.1, U3.16 (O1a)
unnamed: R10.1, U3.14 (O2a)
unnamed: R11.1, U3.12 (O3a)
unnamed: R12.1, U3.9 (O0b)
unnamed: R13.1, U3.7 (O1b)
unnamed: R14.1, U3.5 (O2b)
unnamed: R15.1, U3.3 (O3b)
Q: J5.23, J6.25, J9.2, JP8.3, U1.3, U2.4 (Q)
RX: J9.4, JP7.3, U1.5
SC0: J5.6, U2.6 (SC0), U3.8 (I3a)
SC1: J5.5, J6.29, U2.5 (SC1), U3.11 (I0b)
SLOT1_CS: JP2.1, JP3.1, U5.20 (~CS)
SLOT2_CS: JP2.3, JP3.3, U6.20 (CS)
TPA: J5.8, U2.34 (TPA), U3.4 (I1a), U4.11 (LE)
TPB: J5.7, J6.31, U2.33 (TPB), U3.6 (I2a)
TX: J9.3, JP8.2
VCC: C1.1, C2.1, C3.1, C4.1, C5.1, C6.1, J5.18, J6.2, J6.40, J7.1, J8.5, J9.1, JP4.1, JP5.1, JP6.3, R1.2, R2.2, R3.2, R4.2, R5.2, R6.2, R7.2, U1.14 (VCC), U2.16 (vcc), U2.40 (VDD), U3.20 (VCC), U4.20 (VCC), U5.28 (VCC), U6.28 (VCC)
~CLEAR: J5.19, J6.21, U2.3 (~CLEAR)
~Q: J6.26, JP8.1, U1.4
~WAIT: J5.20, J6.23, U2.2 (~WAIT~)

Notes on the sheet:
RC1802 CPU board

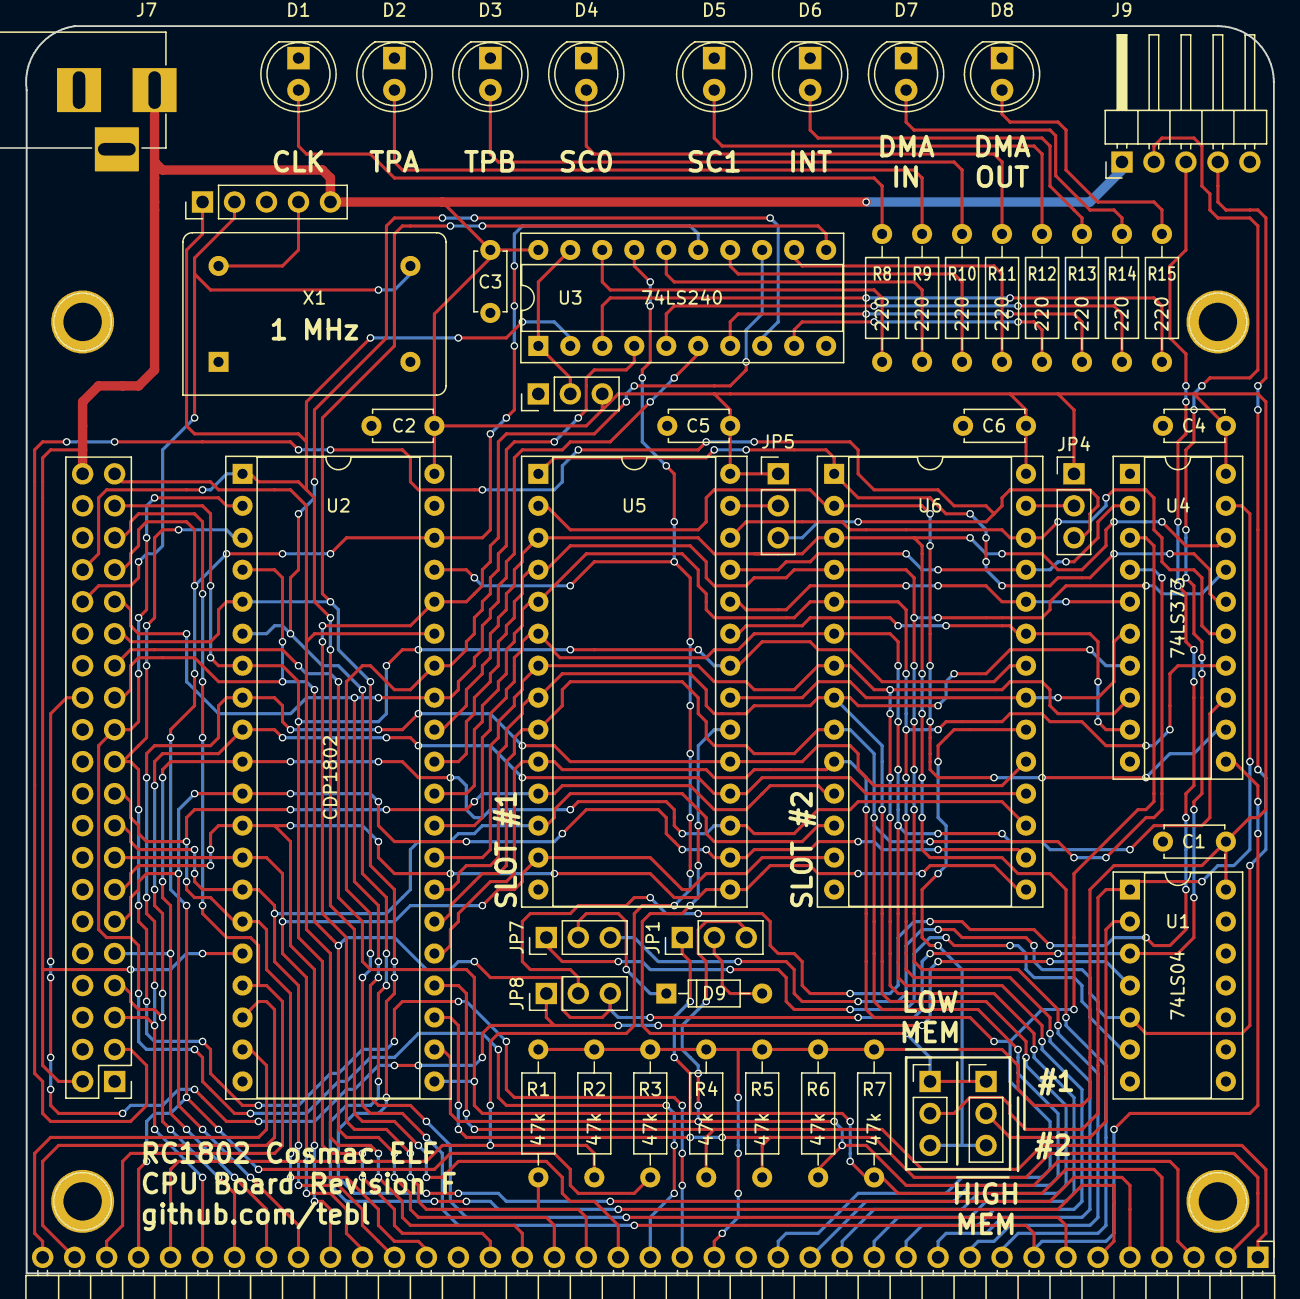
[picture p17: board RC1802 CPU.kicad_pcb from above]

Board: 2 copper layers, 99.1 x 99.1 mm, 54 parts (0 on the bottom side), 77 nets.

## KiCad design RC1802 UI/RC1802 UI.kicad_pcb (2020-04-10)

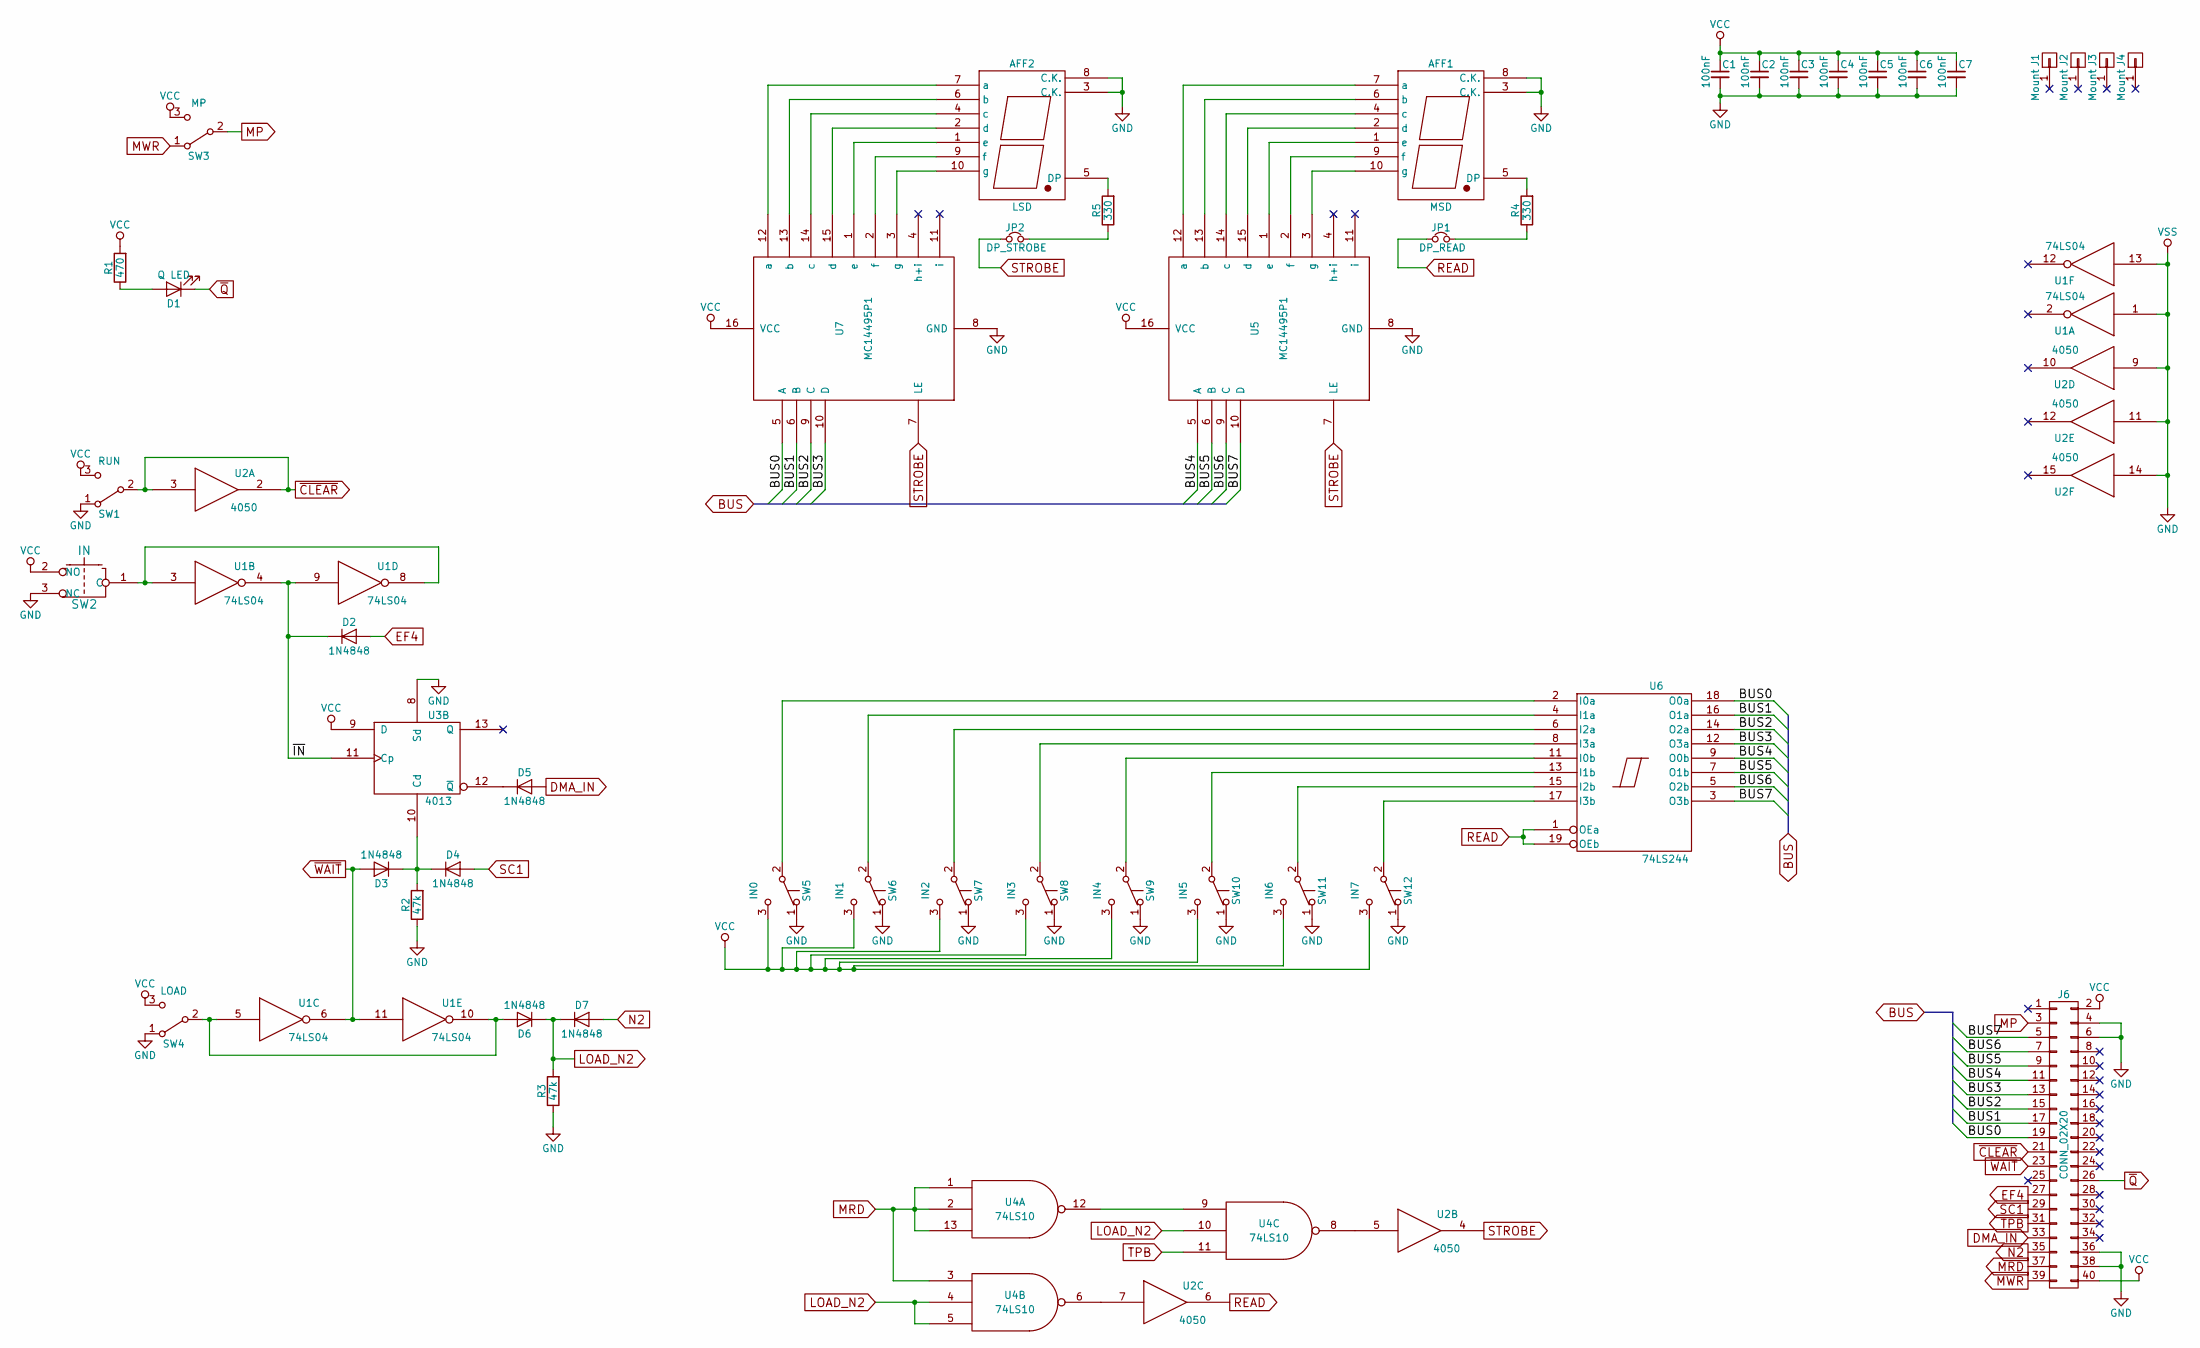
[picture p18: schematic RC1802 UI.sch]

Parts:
AFF1: MSD; 7SegmentLED_LTS6760_LTS6780
AFF2: LSD; 7SegmentLED_LTS6760_LTS6780
C1, C2, C3, C4, C5, C6, C7: 100nF; C_Disc_D4.7mm_W2.5mm_P5.00mm
D1: Q LED; LED_D5.0mm
D2, D3, D4, D5, D6, D7: 1N4848; D_DO-35_SOD27_P7.62mm_Horizontal
J1, J2, J3, J4: Mount; 1pin
J6: CONN_02X20; IDC_Header_Straight_40pins
JP1: DP_READ; Pin_Header_Straight_1x02_Pitch2.54mm
JP2: DP_STROBE; Pin_Header_Straight_1x02_Pitch2.54mm
R1: 470; R_Axial_DIN0207_L6.3mm_D2.5mm_P10.16mm_Horizontal
R2, R3: 47k; R_Axial_DIN0207_L6.3mm_D2.5mm_P10.16mm_Horizontal
R4, R5: 330; R_Axial_DIN0207_L6.3mm_D2.5mm_P10.16mm_Horizontal
SW1: RUN; SPDT_SWITCH
SW2: IN; SPDT_PUSH
SW3: MP; SPDT_SWITCH
SW4: LOAD; SPDT_SWITCH
SW5: IN0; SPDT_SWITCH
SW6: IN1; SPDT_SWITCH
SW7: IN2; SPDT_SWITCH
SW8: IN3; SPDT_SWITCH
SW9: IN4; SPDT_SWITCH
SW10: IN5; SPDT_SWITCH
SW11: IN6; SPDT_SWITCH
SW12: IN7; SPDT_SWITCH
U1: 74LS04; DIP-14_W7.62mm_Socket
U2: 4050; DIP-16_W7.62mm_Socket
U3: 4013; DIP-14_W7.62mm_Socket
U4: 74LS10; DIP-14_W7.62mm_Socket
U5, U7: MC14495P1; DIP-16_W7.62mm_Socket
U6: 74LS244; DIP-20_W7.62mm_Socket

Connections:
/BUS0: J6.19, U6.18 (O0a), U7.5 (A)
/BUS1: J6.17, U6.16 (O1a), U7.6 (B)
/BUS2: J6.15, U6.14 (O2a), U7.9 (C)
/BUS3: J6.13, U6.12 (O3a), U7.10 (D)
/BUS4: J6.11, U5.5 (A), U6.9 (O0b)
/BUS5: J6.9, U5.6 (B), U6.7 (O1b)
/BUS6: J6.7, U5.9 (C), U6.5 (O2b)
/BUS7: J6.5, U5.10 (D), U6.3 (O3b)
/~IN: D2.1 (K), U1.4, U1.9, U3.11 (Cp)
DMA_IN: D5.2 (A), J6.33
EF4: D2.2 (A), J6.27
GND: AFF1.3 (C.K.), AFF1.8 (C.K.), AFF2.3 (C.K.), AFF2.8 (C.K.), C1.2, C2.2, C3.2, C4.2, C5.2, C6.2, C7.2, J6.4, J6.6, J6.36, J6.38, R2.1, R3.1, SW1.1 (A), SW2.3 (NC), SW4.1 (A), SW5.1 (A), SW6.1 (A), SW7.1 (A), SW8.1 (A), SW9.1 (A), SW10.1 (A), SW11.1 (A), SW12.1 (A), U1.1, U1.7 (GND), U1.13, U2.8 (VSS), U2.9, U2.11, U2.14, U3.7 (GND), U3.8 (Sd), U4.7 (GND), U5.8 (GND), U6.10 (GND), U7.8 (GND)
LOAD_N2: D6.1 (K), D7.1 (K), R3.2, U4.4, U4.5, U4.10
MP: J6.3, SW3.2 (B)
MRD: J6.37, U4.1, U4.2, U4.3, U4.13
MWR: J6.39, SW3.1 (A)
N2: D7.2 (A), J6.35
unnamed: AFF1.1 (e), U5.1 (e)
unnamed: AFF1.2 (d), U5.15 (d)
unnamed: AFF1.4 (c), U5.14 (c)
unnamed: AFF1.5 (DP), R4.2
unnamed: AFF1.6 (b), U5.13 (b)
unnamed: AFF1.7 (a), U5.12 (a)
unnamed: AFF1.9 (f), U5.2 (f)
unnamed: AFF1.10 (g), U5.3 (g)
unnamed: AFF2.1 (e), U7.1 (e)
unnamed: AFF2.2 (d), U7.15 (d)
unnamed: AFF2.4 (c), U7.14 (c)
unnamed: AFF2.5 (DP), R5.2
unnamed: AFF2.6 (b), U7.13 (b)
unnamed: AFF2.7 (a), U7.12 (a)
unnamed: AFF2.9 (f), U7.2 (f)
unnamed: AFF2.10 (g), U7.3 (g)
unnamed: D1.2 (A), R1.1
unnamed: D3.1 (K), D4.1 (K), R2.2, U3.10 (Cd)
unnamed: D5.1 (K), U3.12 (~Q)
unnamed: D6.2 (A), SW4.2 (B), U1.5, U1.10
unnamed: JP1.2, R4.1
unnamed: JP2.2, R5.1
unnamed: SW2.1 (C), U1.3, U1.8
unnamed: SW5.2 (B), U6.2 (I0a)
unnamed: SW6.2 (B), U6.4 (I1a)
unnamed: SW7.2 (B), U6.6 (I2a)
unnamed: SW8.2 (B), U6.8 (I3a)
unnamed: SW9.2 (B), U6.11 (I0b)
unnamed: SW10.2 (B), U6.13 (I1b)
unnamed: SW11.2 (B), U6.15 (I2b)
unnamed: SW12.2 (B), U6.17 (I3b)
unnamed: U2.5, U4.8
unnamed: U2.7, U4.6
unnamed: U4.9, U4.12
READ: JP1.1, U2.6, U6.1 (OEa), U6.19 (OEb)
SC1: D4.2 (A), J6.29
STROBE: JP2.1, U2.4, U5.7 (LE), U7.7 (LE)
TPB: J6.31, U4.11
VCC: C1.1, C2.1, C3.1, C4.1, C5.1, C6.1, C7.1, J6.2, J6.40, R1.2, SW1.3 (C), SW2.2 (NO), SW3.3 (C), SW4.3 (C), SW5.3 (C), SW6.3 (C), SW7.3 (C), SW8.3 (C), SW9.3 (C), SW10.3 (C), SW11.3 (C), SW12.3 (C), U1.14 (VCC), U2.1 (VCC), U3.9 (D), U3.14 (VCC), U4.14 (VCC), U5.16 (VCC), U6.20 (VCC), U7.16 (VCC)
~CLEAR: J6.21, SW1.2 (B), U2.2, U2.3
~Q: D1.1 (K), J6.26
~WAIT: D3.2 (A), J6.23, U1.6, U1.11

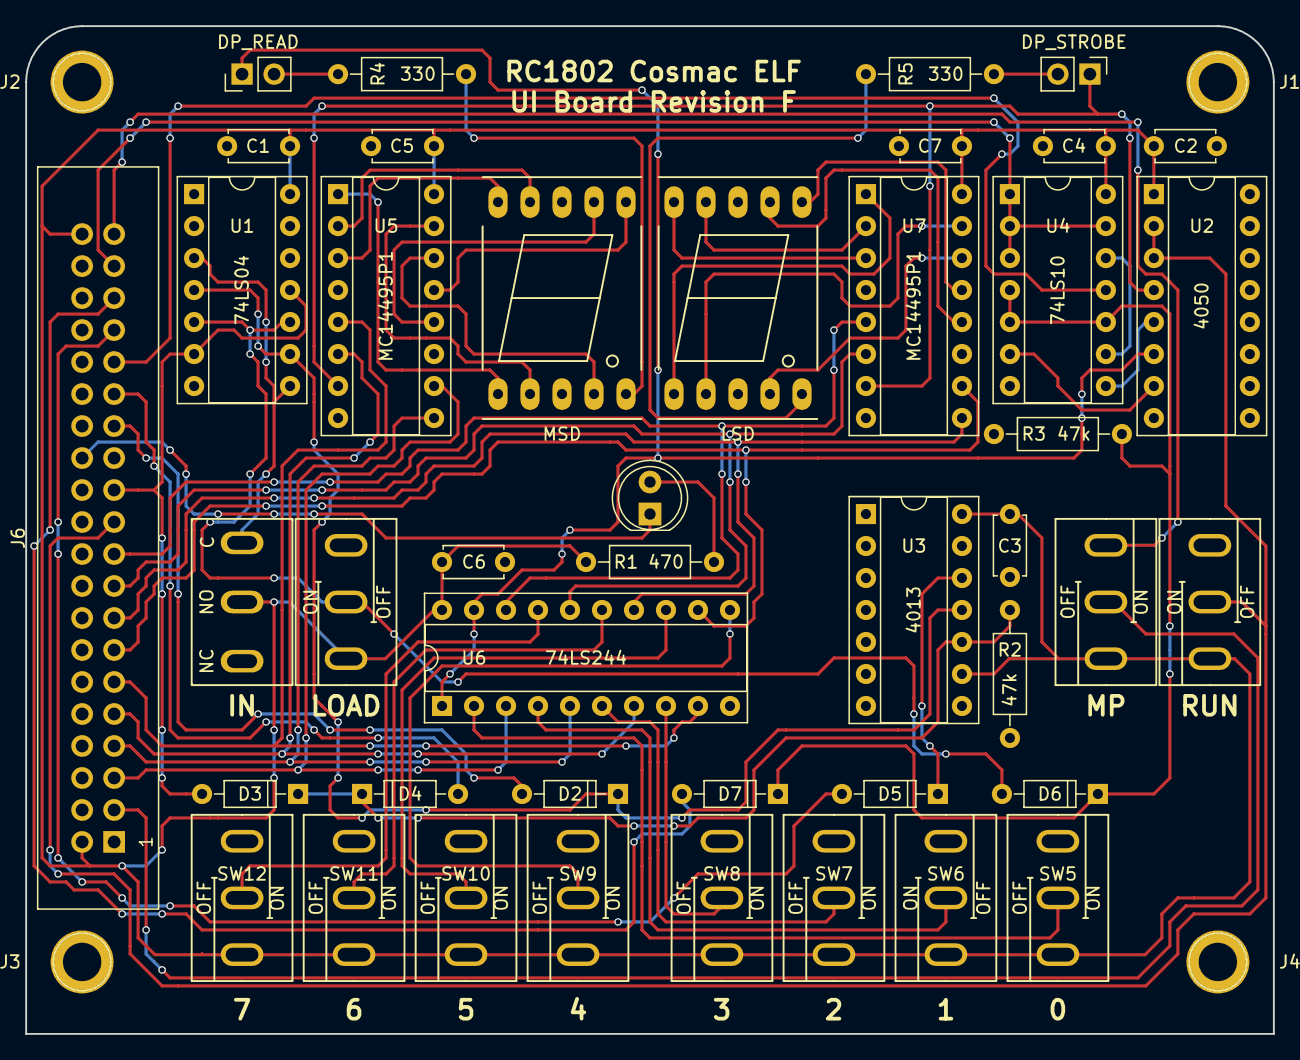
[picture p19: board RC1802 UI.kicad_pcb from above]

Board: 2 copper layers, 99.1 x 80.0 mm, 47 parts (0 on the bottom side), 59 nets.

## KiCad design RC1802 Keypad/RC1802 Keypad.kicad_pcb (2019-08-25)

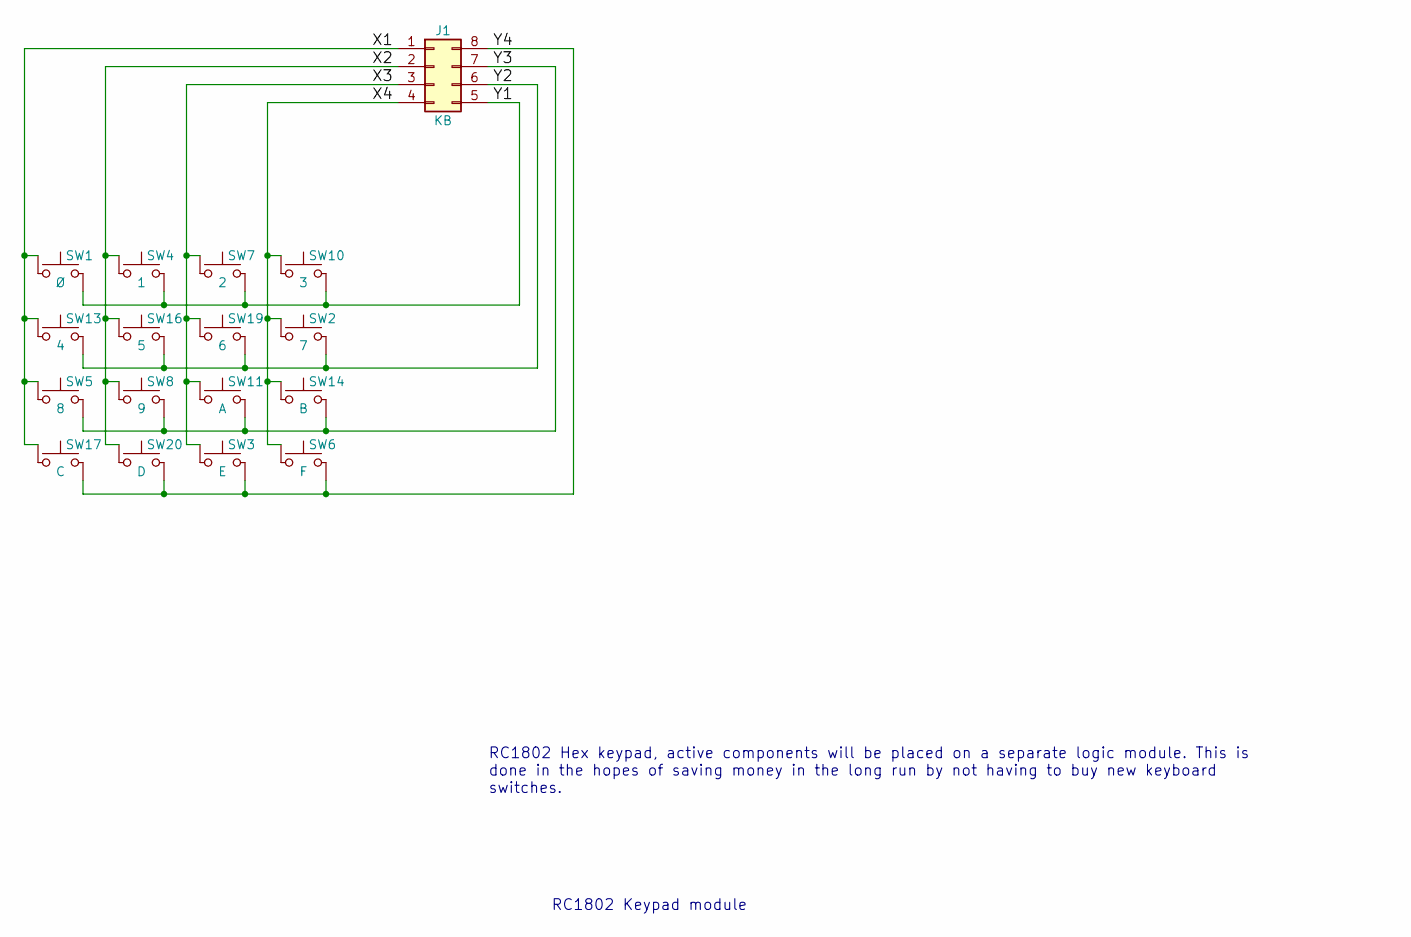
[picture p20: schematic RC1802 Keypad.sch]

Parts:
J1: KB; Pin_Header_Straight_2x04_Pitch2.54mm
SW1: Ø; SW_Cherry_MX_1.00u_PCB
SW2: 7; SW_Cherry_MX_1.00u_PCB
SW3: E; SW_Cherry_MX_1.00u_PCB
SW4: 1; SW_Cherry_MX_1.00u_PCB
SW5: 8; SW_Cherry_MX_1.00u_PCB
SW6: F; SW_Cherry_MX_1.00u_PCB
SW7: 2; SW_Cherry_MX_1.00u_PCB
SW8: 9; SW_Cherry_MX_1.00u_PCB
SW10: 3; SW_Cherry_MX_1.00u_PCB
SW11: A; SW_Cherry_MX_1.00u_PCB
SW13: 4; SW_Cherry_MX_1.00u_PCB
SW14: B; SW_Cherry_MX_1.00u_PCB
SW16: 5; SW_Cherry_MX_1.00u_PCB
SW17: C; SW_Cherry_MX_1.00u_PCB
SW19: 6; SW_Cherry_MX_1.00u_PCB
SW20: D; SW_Cherry_MX_1.00u_PCB

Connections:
/X1: J1.1, SW1.1, SW5.1, SW13.1, SW17.1
/X2: J1.2, SW4.1, SW8.1, SW16.1, SW20.1
/X3: J1.3, SW3.1, SW7.1, SW11.1, SW19.1
/X4: J1.4, SW2.1, SW6.1, SW10.1, SW14.1
/Y1: J1.5, SW1.2, SW4.2, SW7.2, SW10.2
/Y2: J1.6, SW2.2, SW13.2, SW16.2, SW19.2
/Y3: J1.7, SW5.2, SW8.2, SW11.2, SW14.2
/Y4: J1.8, SW3.2, SW6.2, SW17.2, SW20.2

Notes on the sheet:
RC1802 Keypad module
RC1802 Hex keypad, active components will be placed on a separate logic module. This is done in the hopes of saving money in the long run by not having to buy new keyboard switches.

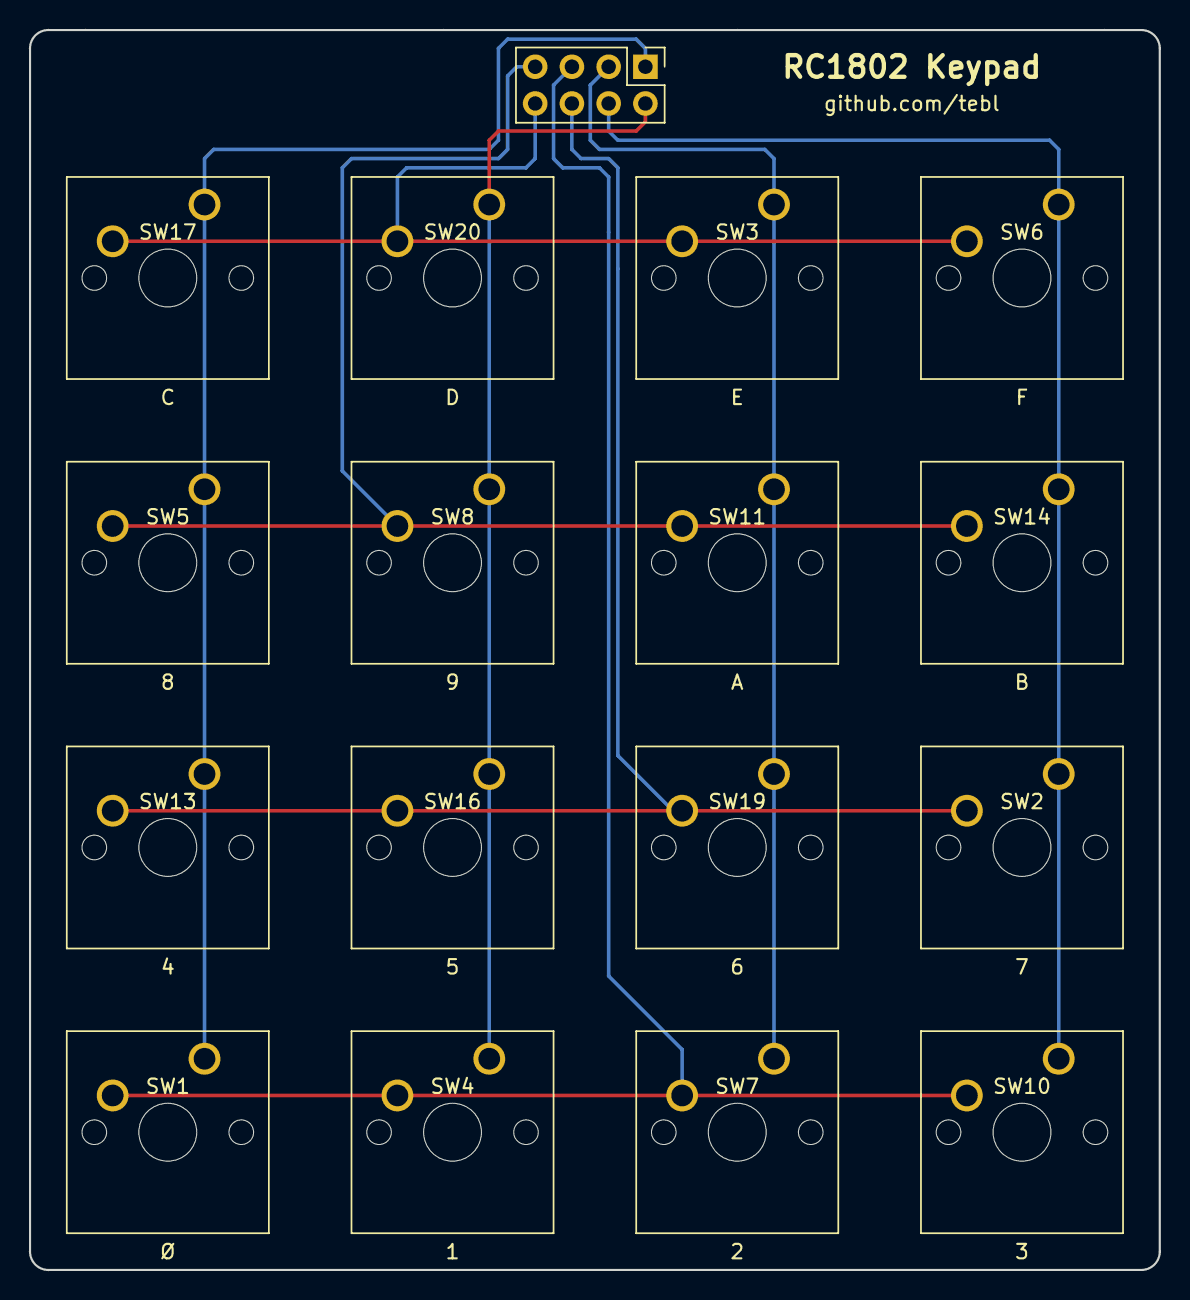
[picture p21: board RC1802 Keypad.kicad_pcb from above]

Board: 2 copper layers, 78.1 x 85.7 mm, 17 parts (0 on the bottom side), 8 nets.

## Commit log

2017-06-18 Completed schematic
    [RC1802 CPU.kicad_pcb, RC1802 CPU.sch]
2017-06-18 Renamed CPU to SBC since it has all components
    [RC1802 SBC.kicad_pcb, RC1802 SBC.sch]
2017-06-18 Added switches.
    [RC1802 SBC.sch]
2017-06-18 Ran out of space :(
    [RC1802 SBC.kicad_pcb, RC1802 SBC.sch]
2017-06-18 Renamed SBC to CPU again.
    [RC1802 CPU.kicad_pcb, RC1802 CPU.sch]
2017-06-18 Copied current CPU board to front to separate functions.
    [RC1802 UI.kicad_pcb, RC1802 UI.sch]
2017-06-19 Completed front panel with exports.
    [RC1802 UI-B.Cu.gbl, RC1802 UI-B.Mask.gbs, RC1802 UI-B.Paste.gbp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]
2018-06-14 Placed PCB components (no tracks)
    [RC1802 CPU.kicad_pcb, RC1802 CPU.sch]
2018-06-20 All tracks layed out
    [RC1802 CPU.kicad_pcb, RC1802 CPU.sch]
2018-06-21 Look at all the pretty silkscreen
    [RC1802 CPU.kicad_pcb]
2018-06-21 Added provisions for using separate clock circuit
    [RC1802 CPU.kicad_pcb, RC1802 CPU.sch]
2018-06-21 Export to Gerber
    [RC1802 CPU-B.Cu.gbl, RC1802 CPU-B.Mask.gbs, RC1802 CPU-B.Paste.gbp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]
2018-08-07 Fixed stupid socket pin count mistake
    [RC1802 CPU.kicad_pcb, RC1802 CPU.sch]
2018-08-07 Tidying up leftover segments
    [RC1802 CPU.kicad_pcb]
2018-08-07 Added Q connector and some silksceen info
    [RC1802 CPU.kicad_pcb, RC1802 CPU.sch]
2018-08-07 Q connector now 4 pins to match speaker and TTL serial
    [RC1802 CPU.kicad_pcb, RC1802 CPU.sch]
2018-08-07 Gerber export
    [RC1802 CPU-B.Cu.gbl, RC1802 CPU-B.Mask.gbs, RC1802 CPU-B.Paste.gbp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]
2018-09-01 Flipped oscillator, silkscreen cleanup
    [RC1802 CPU.kicad_pcb]
2018-09-01 Increased hole sizes for switches
    [RC1802 UI.kicad_pcb]
2018-09-01 Silkscreen cleanup
    [RC1802 UI.kicad_pcb]
2018-09-01 Switched MP and IN
    [RC1802 UI.kicad_pcb]
2018-09-01 Connected VSS and GND
    [RC1802 UI.kicad_pcb, RC1802 UI.sch]
2018-09-01 Removed backplane connector and cleanup
    [RC1802 UI.kicad_pcb, RC1802 UI.sch]
2018-09-01 Moved lower VCC path
    [RC1802 UI.kicad_pcb]
2018-09-01 Revision B export
    [RC1802 UI-B.Cu.gbl, RC1802 UI-B.Mask.gbs, RC1802 UI-B.Paste.gbp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]
2018-09-01 Tied leftover LS04 and 4050 inputs low
    [RC1802 UI.kicad_pcb, RC1802 UI.sch]
2018-09-01 Export new revision B
    [RC1802 UI-B.Cu.gbl, RC1802 UI-B.Mask.gbs, RC1802 UI-B.Paste.gbp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]
2018-09-10 Accidentally swapped VCC and GND on oscillator, no wonder it didn't work :-(
    [RC1802 CPU-B.Cu.gbl, RC1802 CPU-B.Mask.gbs, RC1802 CPU-B.Paste.gbp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]
2018-09-10 Fixed issue with in button, seems I should have read missing datasheet!
    [RC1802 UI.kicad_pcb, RC1802 UI.sch]
2018-09-10 Q signal inverter wrong way around!
    [RC1802 UI.kicad_pcb, RC1802 UI.sch]
2018-09-10 Bus connected in wrong order to hex drivers
    [RC1802 UI.sch]
2018-09-10 Removed resistor array as not in original schematic
    [RC1802 UI.sch]
2018-09-10 Use LED digit DP as STROBE/READ indicator
    [RC1802 UI.sch]
2018-09-11 Added ~Q to UI connector
    [RC1802 CPU-B.Cu.gbl, RC1802 CPU-B.Mask.gbs, RC1802 CPU-B.Paste.gbp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]
2018-09-22 Regenerate netlist
    [RC1802 UI.kicad_pcb, RC1802 UI.sch]
2018-09-22 Use proper switch names to ease use
    [RC1802 UI.kicad_pcb, RC1802 UI.sch]
2018-09-23 UI PCB layout incorporating changes
    [RC1802 UI.kicad_pcb, RC1802 UI.sch]
2018-09-23 Fixed label snafoos
    [RC1802 CPU.sch]
2018-09-23 Fixed tracks missing due to labelling issues
    [RC1802 CPU-B.Cu.gbl, RC1802 CPU-B.Mask.gbs, RC1802 CPU-B.Paste.gbp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]
2018-09-23 Gerber export UI board
    [RC1802 UI-B.Cu.gbl, RC1802 UI-B.Mask.gbs, RC1802 UI-B.Paste.gbp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]
2018-09-23 Gerber export CPU board after adding clockport
    [RC1802 CPU-B.Cu.gbl, RC1802 CPU-B.Mask.gbs, RC1802 CPU-B.Paste.gbp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]
2018-10-02 It all works, though LOAD was upside down...
    [RC1802 UI-B.Cu.gbl, RC1802 UI-B.Mask.gbs, RC1802 UI-B.Paste.gbp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]
2018-10-03 Export new revision D for UI
    [RC1802 UI-B.Cu.gbl, RC1802 UI-B.Mask.gbs, RC1802 UI-B.Paste.gbp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]
2018-10-03 Added jumpers for inverting TX/RX
    [RC1802 CPU.kicad_pcb, RC1802 CPU.sch]
2018-10-09 Added PCBway links to shared projects
2018-10-16 Forgot to regenerate filled zones, so wasted a PCB build :-(
    [RC1802 UI-B.Cu.gbl, RC1802 UI-B.Mask.gbs, RC1802 UI-B.Paste.gbp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]
2018-10-17 Wider power tracks and moved clockport
    [RC1802 CPU-B.Cu.gbl, RC1802 CPU-B.Mask.gbs, RC1802 CPU-B.Paste.gbp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]
2018-10-17 Changed UI connector
    [RC1802 UI-B.Cu.gbl, RC1802 UI-B.Mask.gbs, RC1802 UI-B.Paste.gbp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]
2018-10-17 Added clock in and out to UI connector
    [RC1802 CPU-B.Cu.gbl, RC1802 CPU-B.Mask.gbs, RC1802 CPU-B.Paste.gbp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]
2019-08-18 Fixed DMA_OUT fault in schematic and layout
    [RC1802 CPU-B.Cu.gbl, RC1802 CPU-B.Mask.gbs, RC1802 CPU-B.Paste.gbp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]
2019-08-25 Keypad layout done
    [RC1802 Keypad.kicad_pcb, RC1802 Keypad.sch]
2019-08-25 Keypad gerber export
    [RC1802 Keypad-B.Cu.gbl, RC1802 Keypad-B.Mask.gbs, RC1802 Keypad-B.Paste.gbp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]
2020-04-10 CPU revision D errata for shorted pins
    [RC1802 CPU.sch, RC1802 UI.sch]
2020-04-10 KiCad 5 update, both boards now marked F to match (without any actual changes)
    [RC1802 CPU-2020-04-10-18-42-11.sch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]
